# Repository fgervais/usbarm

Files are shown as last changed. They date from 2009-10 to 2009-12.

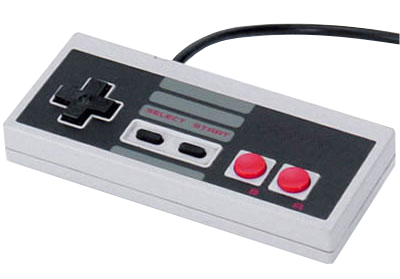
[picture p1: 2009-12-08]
Rapport/images/nes_controller1.png

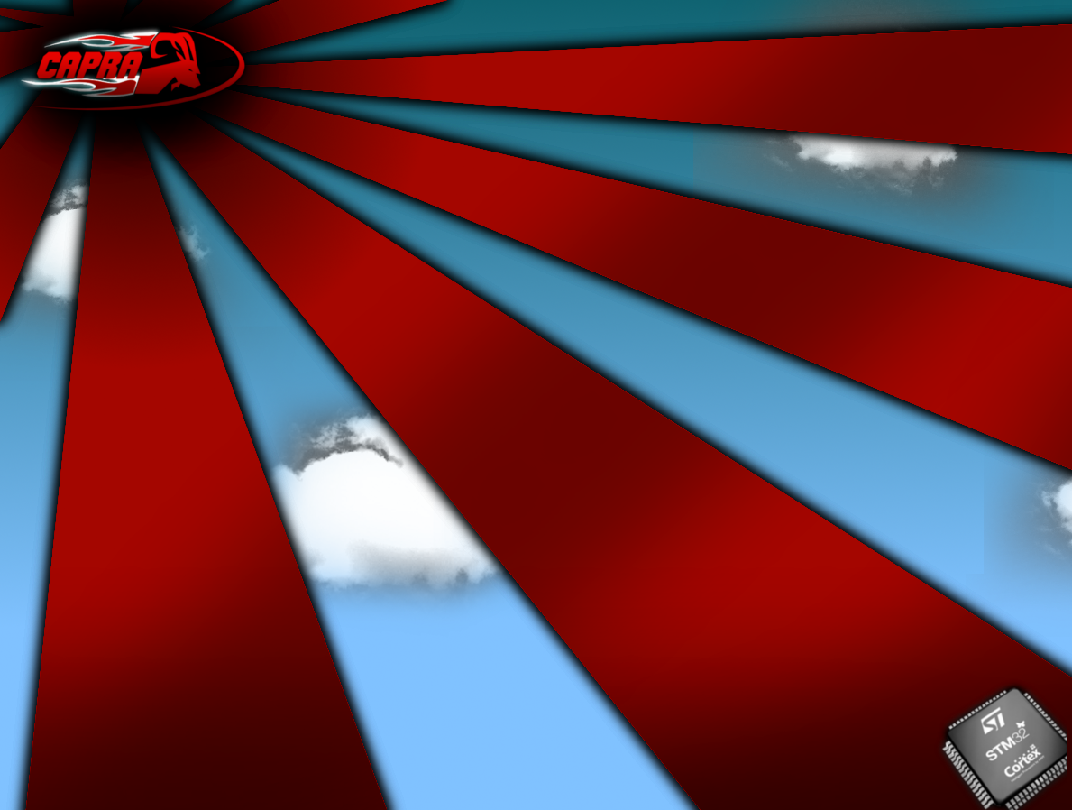
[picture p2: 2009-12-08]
Rapport/images/CapraPowerPointbg.png

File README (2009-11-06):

Note: This template has been built from a template done by Peter Harrison. His original README has been keept but renamed as README_LEGACY.
------------------

This folder contain...

These are some impotant things to keep in mind:

- There might be some peripheral conflict since some/all GPIO are multiplexed.

Here is how thing are done and what are the bad things that could happen.
The first time you ask STM32F103 class for something, it will configure everything
and the instance returned is guaranteed to work. However, it will not configure it
again as long as the program is running. So if you have two different peripheral 
that are using the same IOs, as soon has you ask for the second one, the first 
one will stop working.

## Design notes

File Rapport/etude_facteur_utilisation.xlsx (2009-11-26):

Fréquence d’opération SPI (Mhz) | Temps de la plus longue transaction (ms) | Temps du traitement (ms) | Facteur d'utilisation du processeur pour le service USB
0.28125 | 1.7030 | 0.1101 | 170.30%
0.5625 | 0.9065 |  | 90.65%
1.125 | 0.5083 |  | 50.83%
2.25 | 0.3092 |  | 30.92%
4.5 | 0.2097 |  | 20.97%
9 | 0.1599 |  | 15.99%
18 | 0.1350 |  | 13.50%

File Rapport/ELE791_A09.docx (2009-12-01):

ÉCOLE DE TECHNOLOGIE SUPÉRIEURE

UNIVERSITÉ DU QUÉBEC

rapport technique

PRÉSENTÉ À L’ÉCOLE DE TECHNOLOGIE SUPÉRIEURE

DANS LE CADRE DU PROJET DE FIN D’ÉTUDES

Restructuration du système de télécommandes pour les robots du club étudiant Capra

par

gervais, François

ST-onge, Rémi

présenté à

Jean-françois boland

montréal, le mercredi 9 décembre 2009

<titre du rapport TECHNIQUE>

<NOM, Prénom>

RÉSUMÉ

<Texte interligne simple>

TABLE DES MATIÈRES

Page

LISTE DES TABLEAUX

Page

LISTE DES FIGURES

Page

LISTE DES ABRÉVIATIONS, SIGLES ET ACRONYMES
Nom : | Description :
AI : | L'intelligence artificielle est défini par l’un de ses créateurs, Marvin Lee Minsky, comme « la construction de programmes informatiques qui s’adonnent à des tâches qui sont, pour l’instant, accomplies de façon plus satisfaisante par des êtres humains car elles demandent des processus mentaux de haut niveau tels que : l’apprentissage perceptuel, l’organisation de la mémoire et le raisonnement critique » http://fr.wikipedia.org/wiki/Intelligence_artificielle
ARM | Nom du manufacturier produisant le microcontrôleur que nous utilison
Bloc d'alimentation: | Le bloc d'alimentation est la composante qui fournis les tensions exigés par tous les composantes du robots. Le bloc utilise les batteries DC 24v et génère des tensions de 24v, 12v, 5v et 3.3v. C'est tensions alimentent l'ordinateurs, l'écran, tous les capteurs ainsi que les récepteurs de télécommandes et le contrôleur.
Capteurs : | Le terme Capteur signifie, dans le cas de nos robots, l'ensemble de périphérique utilisé pour détecté des objet et obstacles ainsi que pour se positionner. Les robots du club étudiant Capra utilisent une caméra, laser SICK LMS291, une boussole et accéléromètre en 3 dimensions, ainsi qu'un GPS NovAtel possédant une borde différentielle.
Contrôleur: | Composante crée par le club étudiant Capra permettant d'effectuer un lien entre l'ordinateur des robots et les interfaces d'entrées et sortie utilisé par le robots. Le controleur utilise un lien CanBUS pour communiquer avec l'ordinateur et utilise un port série RS232 pour communiquer avec la « drive » de moteurs tout en ayant la possibilité de contrôler les divers entrées et sortie du système. Le contrôleur est aussi utilisé pour faire l'asservissement des moteurs du robots
Cortex-M3 | Famille du microcontrôleur utilisé
CRC | Cyclic Redondancy Check
DC: | Le courant continu (qui peut être abrégé par CC, ou DC, pour Direct Current), est un courant électrique unidirectionnel : le courant circule continuellement dans le même sens, le déplacement des électrons se fait toujours dans le même sens. http://fr.wikipedia.org/wiki/Courant_continu
DE2 | Carte de développement produite par Terasic
Diagramme de Gantt: | « Le diagramme de Gantt est un outil utilisé en ordonnancement et gestion de projet et permettant de visualiser dans le temps les diverses tâches composant un projet. Il permet de représenter graphiquement l'avancement du projet. » http://fr.wikipedia.org/wiki/Diagramme_de_Gantt
Drive : | Le mot Drive vient de l'anglais et représente un contrôleur de moteur. Puisque notre robot contient déjà une pièce qui effectue le contrôle des moteurs, soit le contrôleur, nous utilisons le terme « drive » pour désigner le contrôleur de moteur Roboteq Ax1500. Il s'agit de la pièce qui gère la puissance de nos moteurs en lien avec des commandes RS232 reçu.
ÉLÉ | Nous parlons régulièrement de Batterie ÉLÉ, ou de la partie ÉLÉ du robot. Le robot est divisé en deux partie, soit par la partie électrique qui contient l'ordinateur, écran, bloc d'alimentation, le contrôleur ainsi que tous les capteurs utilisé dans le robots et bien entendu une batterie
HID | Human Interface Device
I/O | I/O vien de l'anglais, désignant les entrées et sortie d'un systeme. Il s'agit de l'abréviation de Input/Output
LED: | Une diode électroluminescente, abrégée sous les sigles DEL ou, plus couramment, LED (pour light-emitting diode) est un composant électronique capable d’émettre de la lumière lorsqu’il est parcouru par un courant électrique. http://fr.wikipedia.org/wiki/Diode_C3%A9lectroluminescente
Microcontrôleur: | Un microcontrôleur est un circuit intégré qui rassemble les éléments essentiels d'un ordinateur : processeur, mémoires et interfaces d'entrées-sorties. Les microcontrôleurs se caractérisent par un plus haut degré d'intégration, une plus faible consommation électrique, une vitesse de fonctionnement plus faible et un coût réduit par rapport aux microprocesseurs polyvalents utilisés dans les ordinateurs personnels. http://fr.wikipedia.org/wiki/Microcontr%C3%B4leur
MEC | La partie MEC du robot désigne la partie alimenté par la batterie MEC du robot. Elle est constitué de la « drive » de moteur et des moteurs eux même ainsi qu'une batterie.
Mode Intelligence artificielle | Le mode « Intelligence artificielle » est un mode de réception de la drive de moteur. Lorsque la drive est programmé en mode « Intelligence artificielle », elle s'attend à recevoir des données dans un protocole de communication RS232 qui ont le format !A7F. Ce qui signifie que le moteur A doit tourner à une vitesse de 7F (127) ce qui est la valeure maximal.
Mode Télécommande | Le mode « télécommande » est un mode de réception de la drive de moteur. Lorsque la drive est programmé en mode « télécommande », elle s'attend à recevoir des données sous forme de PWM, soit un signal de forme carré ou la largeur de la bande détermine la vitesse de chaque moteur.
NAK | Non Acknowledge
NES | Nintendo Entertainment System
Nintendo | Auteur de la console Nintendo Entertainment System
PID | Packet Identification
PWM : | La modulation de largeur d'impulsions (en anglais : Pulse Width Modulation, soit PWM), est une technique couramment utilisée pour synthétiser des signaux continus à l'aide de circuits à fonctionnement tout ou rien, ou plus généralement à états discrets.Le principe général est qu'en appliquant une succession d'états discrets pendant des durées bien choisies, on peut obtenir en moyenne sur une certaine durée n'importe quelle valeur intermédiaire. http://fr.wikipedia.org/wiki/Modulation_de_largeur_d%27impulsion
Récepteur : | Le récepteurs est la composante qui reçois les signaux électro-magnétique provenant des télécommandes que nous utilisons. Nous avons deux récepteurs similaire qui sont utilisé pour récupérer les signaux provenant de la télécommande du robot ainsi que les signaux provenant de l'arrêt d'urgence sans fil.
RS232 : | Le RS-232 est une norme standardisant un bus de communication de type série sur trois fils minimum (électrique, mécanique et protocole). Disponible sur presque tous les PC jusqu'au milieu des années 2000. http://fr.wikipedia.org/wiki/RS-232
SPI | Serial Peripheral Interface
Télécommande : | La télécommande est le périphérique que nous utilisons pour contrôler nos robots à distance par une intervention humaine. Cette télécommande est très pratique quand vient le temps de déplacer nos robots ou de faire des démonstrations publique.
UART: | UART est un terme qui vient de l'anglais, ce sont les initiales de : Universal Asynchronous Receiver Transmitter. L'UART est donc un émetteur-récepteur asynchrone universel. En langage courant, c'est le composant utilisé pour faire la liaison entre l'ordinateur et le port série . L'ordinateur envoie les données en parallèle (autant de fils que de bits de données). Il faut donc transformer ces données pour les faire passer à travers une liaison série qui utilise un même fil pour faire passer tous les bits de données. http://fr.wikipedia.org/wiki/UART
USB : | L’Universal Serial Bus (USB) est un bus informatique à transmission série servant à connecter des périphériques informatiques à un ordinateur. Le bus USB permet de connecter jusqu'à 127 périphériques à chaud et en bénéficiant du Plug and Play. http://fr.wikipedia.org/wiki/Universal_Serial_Bushttp://fr.wikipedia.org/wiki/Courant_continu
XBOX | Marque déposé de Microsoft pour sa console de jeux vidéo

# INTRODUCTION

Le club Capra a été fondé en 1996 par des étudiants, passionné de robotique, de l'école de technologie supérieure. Capra se spécialise dans la construction de robots autonome qui tentent de relever des défis au niveau de compétitions internationale dans le domaine de la navigation autonome. Grâce à l'implication d'une vingtaine de membre actif dans plusieurs domaines du génie tel que Mécanique, Électrique, Logiciel, Ti, Opérations et logistique ainsi qu'en production automatisée, le club est parvenu, cette été, à remporter un trophée pour une 3ieme place à la compétition de l'ION Automow (Institute of Navigation).

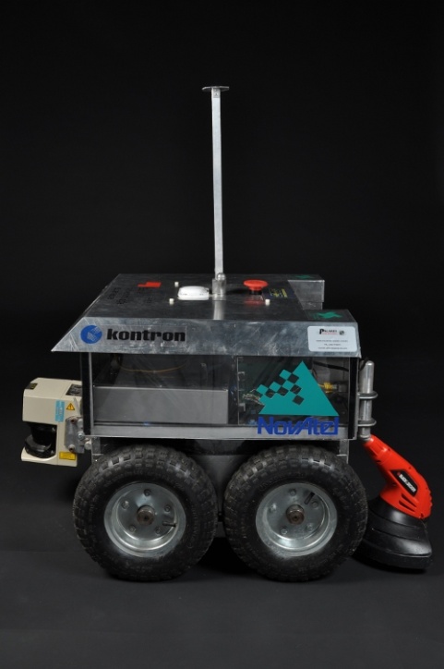
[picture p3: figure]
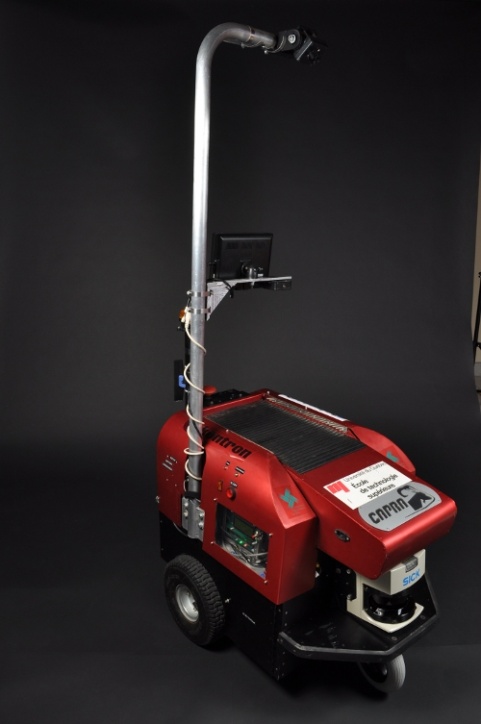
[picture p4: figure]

Pour le moment, le club Capra utilise deux robots fiables, soit RS3 et Herbinator. RS3, participe une compétition de parcours à obstacle dans lequel il doit parcourir un trajet qui lui est inconnu et qui est remplis d'embuche. Il doit atteindre la ligne d'arrivée, sans aucune intervention humaine plus rapidement que les autres équipes. Herbinator, pour sa part, est une tondeuse à gazon autonome capable de tondre des terrains de formes différentes tout en étant capable d'éviter les fleurs et le chien qui se ballade sur le terrain de la compétition.

Figure 2 RS3

Figure 1 Herbinator

Les deux robots, qui effectue des taches bien différente, ont des caractéristiques électronique et logicielle très semblables. Ils utilisent une panoplie de capteurs de toute sorte reliée à un ordinateur qui effectue le traitement de toutes ces données pour s'orienter et se déplacer en toute quiétude.

Le club travaille présentement à améliorer et maintenir ces deux robots dans le but d'obtenir une première place lors d'une future compétition. Cette année, nous nous dirigerons vers

C’est donc par l’expérience des compétitions passés, les démonstrations de robotiques auxquelles nous participons dans le but de représenter l’école de technologie supérieure de Montréal ainsi que les nombreux tests effectué tout au long de l’année que nous avons remarqué plusieurs problèmes relié au système de gestion des télécommandes de nos robots.

Cette année, nous partirons, dans la semaine du 30 mai 2010, deux équipes distincte, avec deux robots distincts à deux compétitions qui se dérouleront en même temps en sol américain. L’une sera à détroit dans l’état du Michigan et l’autre à Dayton dans l’état de l’Ohio.

Au cours de la prochaine année, le club étudiant aimerait régler des problématiques de mobilité des robots en améliorant l'implémentation de la télécommande qui permet de contrôler le robot à distance. Ces télécommandes sont utilisé lors des divers événements publicitaires ou de démonstrations publique que nous participons ainsi que lors de la réalisation de test ou l'on doit déplacer les robots dans des endroits stratégiques.

# CHAPITRE 1 Analyse de la problématique

## 1.1 Explication du système actuel

Pour bien être en mesure de comprendre les problèmes reliés au système de télécommande de nos robots, il importe de comprendre le fonctionnement de ceux-ci. Nous allons donc débuter par vous expliquer le principe de fonctionnement de nos robots.

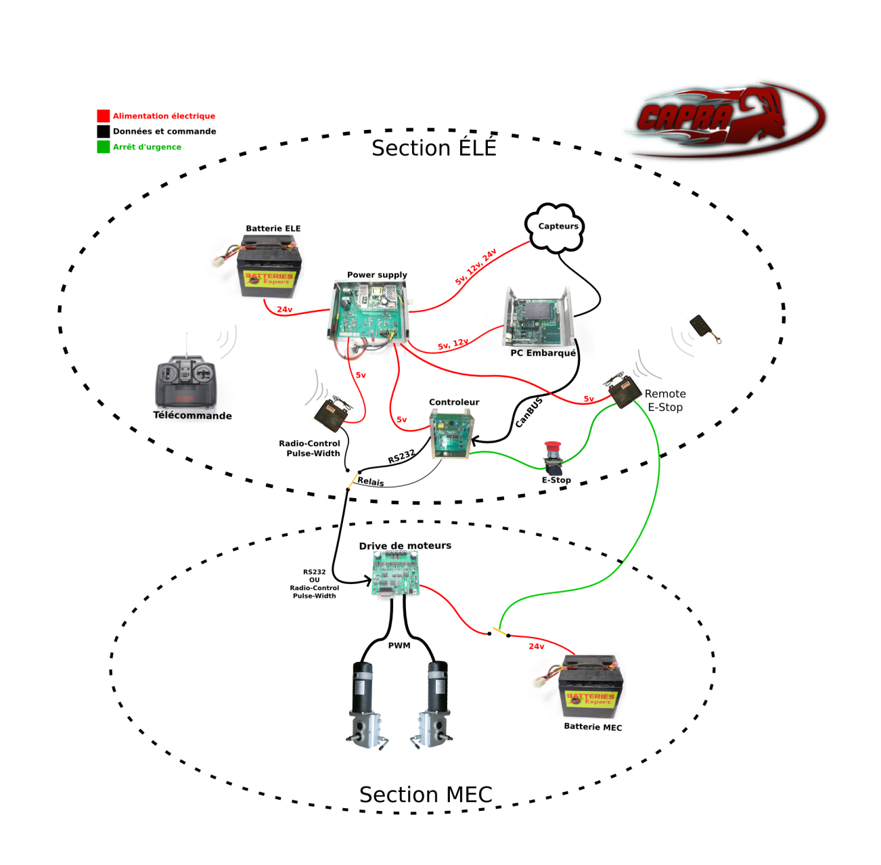
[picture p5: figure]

Figure 2 Schéma actuel des robots

Ce diagramme représente les diverses composantes du robot en lien avec le système de télécommande.

Globalement, le système actuel est divisible en deux partie. Une partie ÉLÉ et une partie MEC. La partie MEC est alimentée par la batterie MEC et contient la « drive » de moteur ainsi que les deux moteurs. La partie ELE, pour sa part, est alimenté par la batterie ELE et contient l'ordinateur embarqué, tous les capteurs, le contrôleur, le bloc d'alimentation, ainsi que les deux télécommandes et récepteurs. Les alimentations des deux parties sont importantes parce qu'elles sont, en bonne partie, une sources des problèmes reliés aux télécommandes. Nous pouvons aussi apercevoir dans le schéma le système d'arrêt d'urgence en vert.

La partie la plus importante se trouve à être la chaine de commande des moteurs. Pour commencer, les données peuvent provenir de l’intelligence artificielle qui se trouve dans le PC embarqué du robot. Les commandes sont transmises au contrôleur par le biais d’un port CANBUS. Par la suite, le contrôleur transmet ces données à la drive de moteur par un lien RS232 en passant par un relais qui aiguille les diverses sources de données pouvant se rendre à la drive. Finalement, la drive de moteur exécute les commande en envoyant les bonnes tensions aux moteurs.

Dans un autre ordre d’idée, il est possible d’utiliser la télécommande des robots. Le récepteur de cette télécommande utilise deux PWM ou la modulation de la largeur de bande représente l’état des deux contrôles sur la télécommande. Notre drive de moteurs est en mesure d’interpréter ces signaux si elle est programmée dans le mode PWM. Donc, pour utiliser cette télécommande, le contrôleur doit envoyer un message à la drive pour la programmer dans le mode PWM et ensuite changer l’état du relais pour aiguiller ce dernier sur l’entrée du récepteur de la télécommande. Si nous désirons revenir en mode intelligence artificielle, le contrôleur modifie l’état du relais pour aiguiller l’entrée sur le lien RS232 provenant du contrôleur et envoie encore une fois un message à la drive de moteur de se programmer en mode RS232.

De plus, les alimentations relié au système ont aussi une importance dans la problématique que nous allons vous expliquer.

Selon le diagramme, nous constatons aussi que les divers récepteurs et pièces sont tous alimenté par le bloc d’alimentation principale à l’exception de la drive de moteur qui elle est alimenté par la batterie Mec du robot. La drive de moteur se trouve donc sur une alimentation séparé du reste du robot.

## 1.2 Division en sous-problèmes

Cette structure nous apporte plusieurs problèmes de toute sorte.

Premièrement, la télécommande actuelle ne fonctionne que sur une très courte distance et la réception est, très souvent, mauvaise. Parfois le robot ne bouge plus du tout ou se déplace de manière très saccadé. La solution devra donc permettre une réception plus fiable et sur une plus grande distance.

De plus, la télécommande utilisée par Capra consume énormément et rapidement les piles. Plus les piles deviennent faible dans la télécommande, plus la réception est mauvaise par les robots. Les télécommandes utilisent chacune 8 piles AA et nous ne disposons pour l'instant que d'un seul chargeur permettant de charger 8 piles à la fois. Cette charge prend environ une journée complète. Pour charger les piles de nos deux télécommandes, nous devons impérativement les charger en deux jours, en s'assurant que quelqu'un soit présent au local du club étudiant pour effectuer une rotation des piles. La gestion de cette charge étant effectué par plusieurs personnes et la communication au sein du club étudiant étant relativement déficiente, la charge de ces piles est un véritable cauchemar. La solution devra donc faciliter le cycle de charges des piles de télécommandes.

Par la suite, les piles utilisées dans les télécommandes se déchargent par eux même. Si les piles sont oubliées dans la télécommande, malgré le fait que cette dernière soit éteinte, les piles se vident complètement en 24 heures. Si nous enlevons les piles de la télécommande, elles se vident tout de même par elle même en deux semaines. Il est donc impossible pour nous de tenir les piles chargé en tout temps. Si nous avons besoin d'utiliser la télécommande rapidement, les chances sont très faibles que nous ayons des piles chargées.

Ensuite, la configuration actuelle de la télécommande implique que la drive de moteur soit configuré en mode « Télécommande » pour traiter les signaux provenant de la télécommande et en mode « Intelligence artificielle » pour traiter les signaux provenant de l'intelligence artificielle. Cette programmation cause beaucoup de problèmes parce qu'elle n'est pas fiable et qu'il est difficile pour nous de nous assurer que la « drive » est dans le mode désirée. Il arrive fréquemment que nous devons brancher un ordinateur dans la « drive » pour la reprogrammer dans le but de pouvoir utiliser la télécommande. Cette programmation est expliqué par le fait que l'intelligence artificielle utilise le protocole RS232 pour communiquer avec la « drive » et la télécommande utilise un PWM (pulse width modulation) pour transmettre les vitesses de chaque moteurs. De plus, nous avons récemment appris, à l’aide du manuel d’utilisateur de la drive de moteur, que nous pouvons la programmer un maximum de 1000 fois. Pour l’instant, nous la programmons au minimum 3 fois à chaque fois que nous utilisons le robot et nous commençons aujourd’hui à avoir beaucoup de problèmes avec nos drives de moteurs qui sont probablement lié de près à cette indication. Le club Capra désire donc trouver une solution qui permet d'éliminer le besoin de reprogrammer la « drive » de moteur lorsqu'on passe du mode « télécommande » au mode « intelligence artificielle ».

Finalement, lorsque nous désirons utiliser la télécommande pour contrôler les robots, nous devons allumer l'ordinateur du robot, qui lui fait démarrer le bloc d'alimentation qui alimente toutes les composantes électronique du robot (capteur, contrôleur, écran, ordinateur, etc). Le fait de tout alimenter le robot lorsque nous n'utilisons que très peu de matériel devient problématique puisque les piles du robot se vident très rapidement. En mode télécommande, le robot devrait alimenter seulement les composantes nécessaires à la motricité sans alimenter les capteurs, l'ordinateur, l'écran ainsi que tous les autres périphériques inutile au mouvement en mode télécommandé.

## 1.3 Étude de la complexité

<Texte>

# CHAPITRE 2 Choix d’une solution

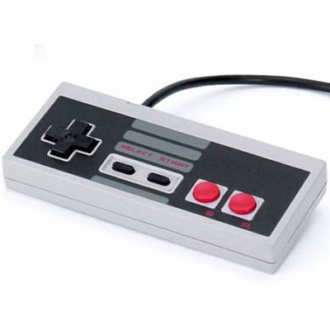
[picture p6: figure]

## 2.1 Jet d’idées

Notre idée de départ était d’intégrer une télécommande de Nintendo 8 bit.

Par la suite, nous avons pensé garder la même télécommande que nous avons actuellement pour nos robots mais en la branchant dans un système qui pourrais convertir le PWM en RS232.

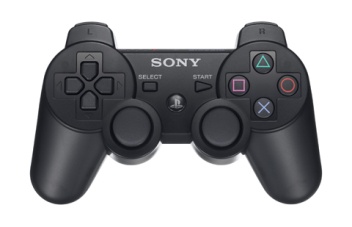
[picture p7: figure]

Nous avons aussi analyser la possibilité d’utiliser une télécommande de Playstation 3 sans fil

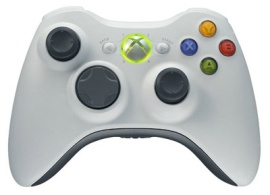
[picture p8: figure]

Et finalement une télécommande de XBOX 360 sans fil

## 2.2 Définition des concepts

Premièrement la télécommande de Nintendo à un grand avantage et un grand désavantage. Premièrement, elle possède un fil. Ce fil nous assure une communication parfaite sans aucune perte de donnée et qui est par le fait même extrêmement fiable. De plus, le protocole de communication de cette télécommande est très simple et facile à intégrer. Son désavantage est qu’elle possède un fil. En effet, notre portée avec le robot se trouve à être très limité. De plus, ces boutons sont de type « Tout ou rien » ce qui pourrais être dangereux dans le cas de notre robot puisque nous n’aurions aucun contrôle de la vitesse du robot mais seulement de la direction dans lequel il se dirige.

Nous avons ensuite analysé la possibilité de garder nos télécommandes actuelles en les modifiant afin de régler certain problèmes. Premièrement, cette télécommande devra être branchée dans une carte qui convertirais le PWM en RS232 pour éliminer le problème de reprogrammation de la drive de moteur. De plus, des piles au lithium ou au nickel devraient être installé pour augmenter la durée de vie de ces dernières. Le fait de modifier les piles devraient, en temps normal, augmenter la puissance de la transmission et par le fait même augmenter la portée du système.

Nous avons ensuite analysé la possibilité d’inclure une télécommande de Playstation 3 sans fil. Cette télécommande à un grand avantage, soit celui de d’avoir une pile qui à fait ces preuves. De plus, la charge de cette pile peut être assurée tout simplement par le branchement d’un câble USB avec un ordinateur personnel. Cette télécommande à par-contre un désavantage. Elle utilise, comme la plupart des télécommandes de sa génération, la technologie Bluetooth pour communiquer avec les récepteurs. Cette technologie bien qu’efficace ne possède une portée que d’environ 10m de rayon, ce qui est insuffisant pour nos besoins.

Finalement, la télécommande de XBOX 360 à aussi le même avantage que la télécommande de Playstation, soit le fait qu’elle possède une batterie au lithium intégré qui se charge par un simple câble USB relié à un ordinateur personnel. Cette télécommande possède un autre avantage de taille : Son protocole de transmission des données se fait par un lien de communication fermé pour lequel les détails ne sont pas vraiment disponibles par Microsoft mais nous savons qu’elle n’utilise pas la technologie Bluetooth. Après avoir effectué plusieurs test, nous nous sommes aperçu que la portée de cette télécommande dépassent amplement nos attentes et nos besoins.

## 2.3 Choix d’une solution

Après de longue discutions, nous avons choisis d’intégrer la télécommande de XBOX à notre système. Ce choix étant risqué étant donné la complexité de l’intégration du USB dans un microcontrôleur, nous avons choisis d’implémenté en parallèle la conversion du PWM de nos commandes actuelles dans notre projet. Le choix de garder la télécommande RF actuelle implique de modifier cette dernière dans le but d’y intégrer une pile au lithium ou au nickel pour augmenter la durée de vie de ces piles ainsi que sa portée. Notre système fonctionnera comme suit : Nous aurons une carte dans laquelle nous brancherons les deux télécommandes (la télécommande de XBOX 360 et la télécommande RF actuelle des robots). Nous brancherons aussi dans cette carte un lien RS232 avec le contrôleur et un autre lien RS232 avec la drive de moteur. De cette manière, en temps normal, nous pourrons simplement répéter les données provenant du contrôleur vers la drive de moteur et ce sera complètement transparent pour l’intelligence artificielle. Les commandes obtenu provenant des télécommandes serons convertis en RS232 sous le même format utilisé par la contrôleur et un système de gestion de priorité (Multiplexeur) aura pour tache de diriger les bons signaux aux bon endroit. De plus, cette carte aura pour tâche d’alimenter les récepteurs des télécommandes et cette carte sera alimenté par la batterie MEC du robot. Ce qui aura pour conséquence d’obtenir la possibilité d’utiliser les télécommande avec tout simplement une batterie MEC et sans même avoir le besoin de démarrer la section ÉLÉ du robot. De plus, le système d’arrêt d’urgence sera modifié pour être controlé à partir de cette carte aussi dans le but de pouvoir débloquer les moteurs sans avoir besoin d’alimenté la section ÉLÉ du robot.

Le schéma suivant explique la solution retenue de manière plus visuelle :

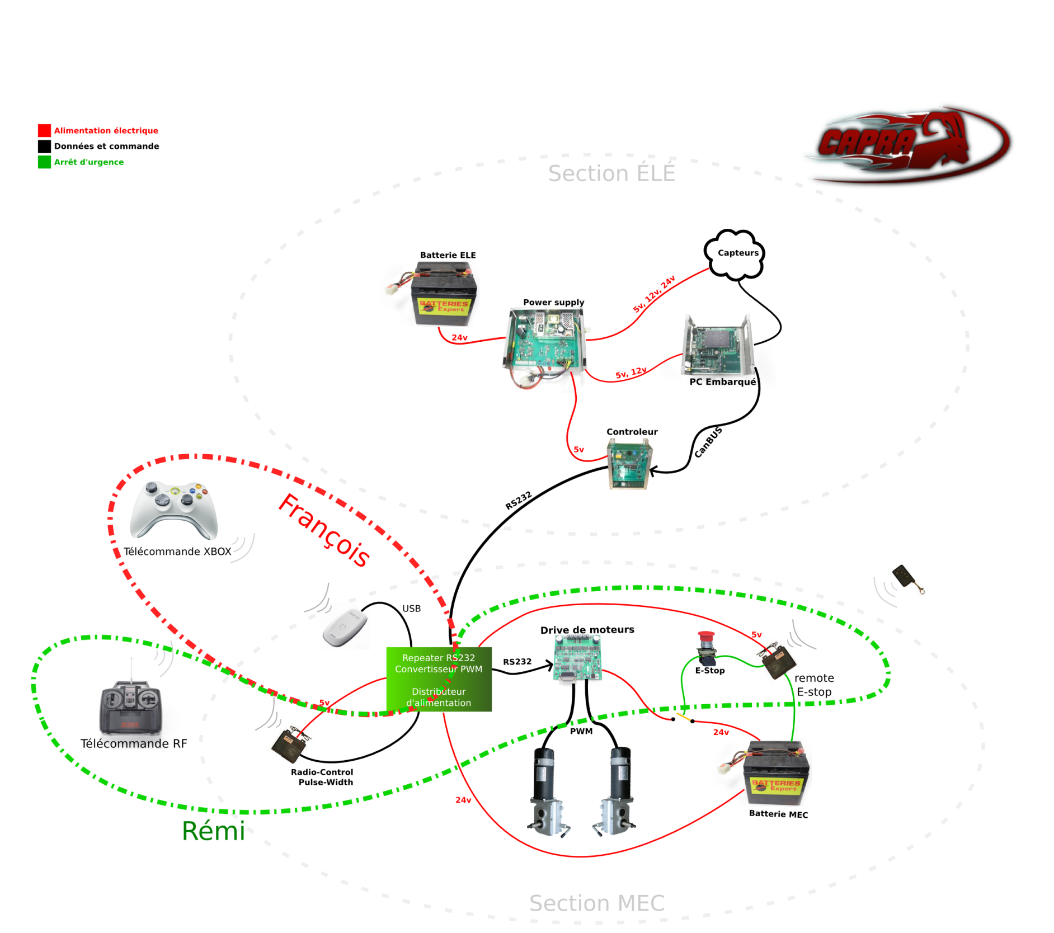
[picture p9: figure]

Figure 3 Schéma de la solution

# CHAPITRE 3 Risques et opportunités

## 3.1 Risques

- Les outils de compilation pour le microcontrôleur choisi ne sont pas disponibles.
- L’utilisation du ARM pourrait être plus complexe que prévue notamment au niveau des interruptions.
- La familiarisation des membres avec la programmation orientée objet dans un microcontrôleur peut être longue
- La création du circuit imprimé peut être plus longue que prévue
- Il pourrait être difficile de trouver un contrôleur USB à la fois facile d’utilisation, avec une bonne documentation et fournis sur une plateforme de prototypage.
- Dépendamment de la vitesse de la communication minimal entre le microcontrôleur et le contrôleur USB, il faudrait peut être produire nous même la plateforme de prototype ce que pourrait grandement jouer sur notre emploi du temps serré.
- La communication entre le microcontrôleur et le contrôleur USB pourrait être difficile à déverminer.
- Comme la vitesse des transactions USB est très rapide, certains problèmes liés à la fréquence élevée pourraient survenir. De plus, les transactions du bus seront difficiles à analyser.
- Plusieurs pièces devront être commandés sur Internet et ceci le plus tôt possible. Ceci rentre en conflit avec le fait que le contrôleur USB n’est pas choisi avant la moitié du projet. De plus le projet ne pourrait surement pas être fait dans les temps si certaines pièces arrivent endommagé ou si nous endommageons une pièce durant le développement.
- Les commandes venant de la télécommande XBOX devront être acquises par la lecture du code de pilotes du noyau linux et l’ingénierie inverse à l’aide d’un analyseur USB. Cette tâche pourrait possiblement être trop compliqué et prendre beaucoup plus de temps que prévue.

Opportunités

- La carte de développent DE2 est disponible à l’école et inclue un contrôleur USB. Celle-ci pourrait possiblement être utilisée.
- Batterie Expert est l’un des commanditaires du club étudiant Capra et pourrais nous donner des informations précieuse quant à la modification de la télécommande actuelle.
- L’existance d’un équipe logiciel au sein du club Capra pourra très probablement nous aider à planifier la gestion du code à l’intérieur du microcontrôleur.
- Labo circuit est aussi un des commanditaires du club étudiant Capra et pourrais possiblement nous fournir le circuit imprimé.

# CHAPITRE 4 Réalisation

## 4.1 Modification de la télécommande actuelle

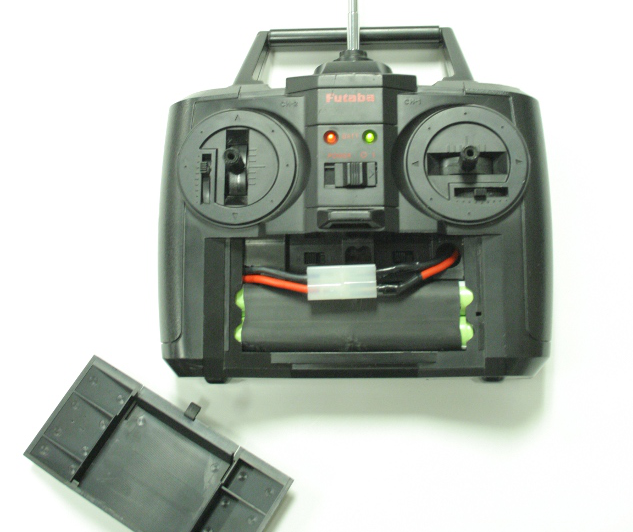
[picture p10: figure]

Pour débuter, nous nous sommes informé au près de Batterie Expert dans le but d’avoir plus amples informations au sujet des piles en général. Après avoir longuement discuté avec eux, nous avons fait un choix de piles. Nous avons choisis d’acheter un chargeur à batterie ainsi que de se faire fabriquer sur mesure un pack de batterie composé de 8 cellules au nickel permettant d’obtenir 2400mah, ce qui était près des spécifications des piles rechargeable que nous disposons au format AA à l’intérieur de notre télécommande. Par la suite, nous avons démonté et modifié l’intérieur de la télécommande à l’aide d’un Dremel dans le but d’enlever complètement le support de batterie AA à l’intérieur dans le but d’y intégré le pack de batteries. Puisque ces batteries ne peuvent maintenant plus être retirées de la télécommande, nous avons utilisé un connecteur à l’intérieur du compartiment à batterie qui permettra de brancher directement la batterie dans le chargeur sans la retirer du compartiment de la télécommande. Cette modification à été apporté a notre télécommande il y a maintenant plus de trois mois, et la pile est encore chargée! La durée de vie de cette pile est incroyable longue. De plus, comme prévu, la portée de la télécommande à été amélioré considérablement.

## 4.2 Choix du microcontrôleur

Notre système comprenant maintenant deux port série, un entrée de capture de PWM ainsi que le besoin d’un support USB Host, nous avions besoin d’un microcontrôleur capable de gérer le tout. Nous avons regardé plusieurs microcontrôleurs soit un Atmega32, un Atmega128 et un Arm Cortex M3. Nous avons finalement choisis le Arm Cortex M3 pour deux raison. Pour commencer, sa puissance de calcul est définitivement plus grande que celle du Atmega32 et du Atmega128. Avec sa fréquence d’horloge cadencée à 72 MHz et plusieurs technologies telles que son pipeline et la possibilité de faire des accès DMA était très prometteur. De plus, ce microcontrôleur nous était inconnu et il est maintenant plus populaire que jamais puisqu’il fait aujourd’hui parti de plusieurs produit qui ont fait leurs preuves comme par exemple le IPhone de Apple qui utilise un autre microcontrôleur Arm très semblable au Cortex M3. Nous avons aussi choisis ce processeur par la possibilité de développer en C++ orienté objet, ce qui nous a permis de concevoir une architecture claire et qui resteras hautement maintenable dans le futur, ce qui est une chose souvent négligé au sein des clubs étudiants.

## 4.3 Compilation et configuration du compilateur

## 4.4 Architecture de notre système (UML)

## 4.5 Communication RS232

## 4.6 Capture du PWM de la télécommande

## 4.7 Implémentation du système de choix de priorité des sources

Notre carte à pour tache de recevoir des données provenant de diverses sources, soit, la télécommande de XBOX 360, du

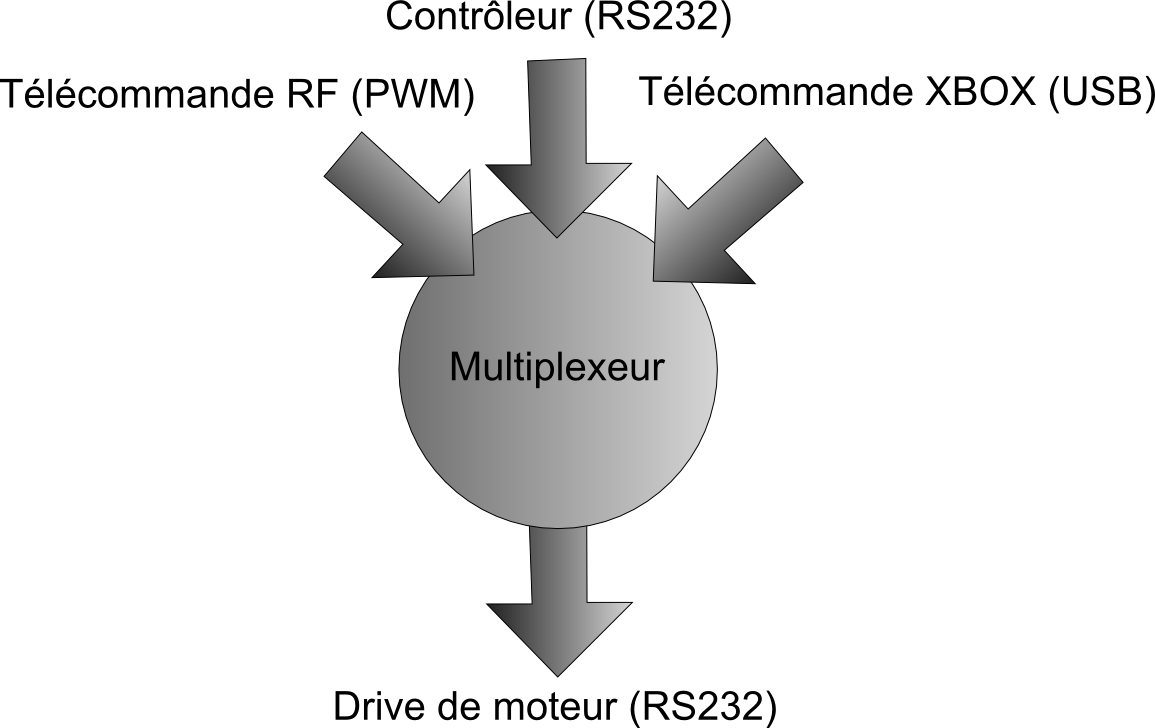
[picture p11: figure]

## 4.8 Choix du contrôleur USB

Le choix du contrôleur n’est pas chose facile. Plusieurs critères doivent être tenu en compte. Dans notre cas, les principaux étaient les suivants en ordre de priorité :

- Support du mode de communication USB par interruption
- Facilité d’accès à la documentation
- Facilité de raccord au microcontrôleur
- Faible à moyen niveau d’abstraction pour ne pas perdre le coté éducatif

Le contrôleur choisi est le MAX3421E de la compagnie Maxim. Cette puce supporte tous les modes de communication USB soit Control, Bulk, Interrupt et Isochronous. De plus, elle est pourvue d’une fiche technique, d’un guide de programmation et d’un exemple couvrant l’énumération. Du coté de l’abstraction, ce contrôleur prend soin de la couche 1 de la communication. En d’autre terme, outre le fait d’envoyer le bon niveau sur les lignes de transmission, il s’occupe d’envoyer le PID, du numéro de séquence des paquets, et d’une certaine partie de la gestion d’erreur. Pour les curieux, ceci consiste principalement en le calcule du CRC et la vérification de celui-ci lors de la réception. De plus, si le CRC permet de détecter une erreur, le contrôleur fera lui-même la demande du même paquet à nouveau. Il est à noter que ceci peut avoir un effet pervers. En effet lors de la conception du pilote, certaines erreurs d’implémentation peuvent être cachées dû au fait que le contrôleur USB redemande automatiquement les paquets en cas d’erreur.

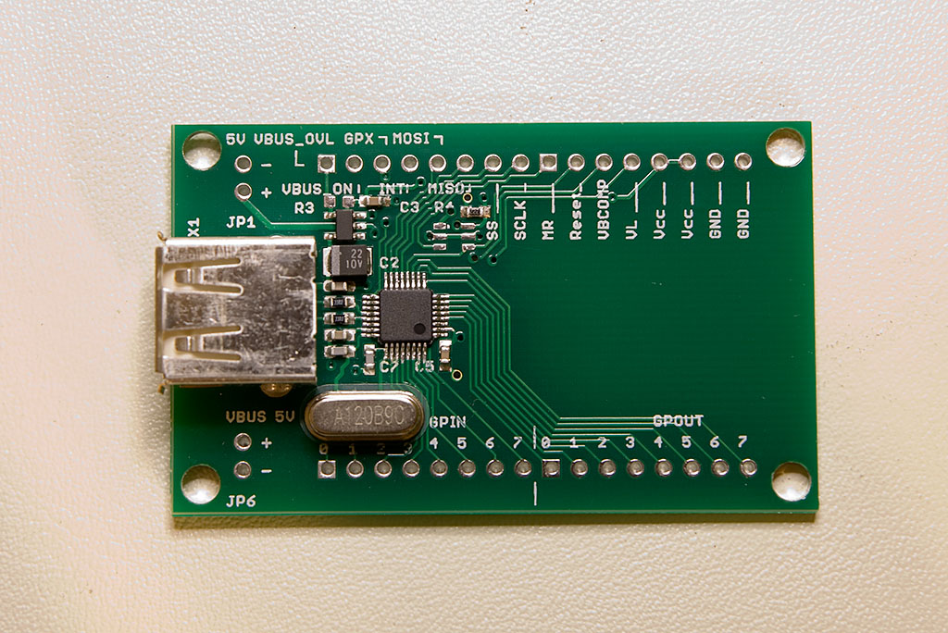
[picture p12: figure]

## 4.9 Conception du pilote USB

### 4.9.1 Détection du périphérique

### 4.9.2 Énumération du périphérique

### 4.9.3 Requêtes HID

Tel que mentionné précédemment le USB comporte plusieurs mode de fonctionnement soit Control, Bulk, Interrupt et Isochronous. Cependant, ceci reste assez large quand on considère tous les périphériques USB disponible. C’est pourquoi ceux qui ont développé la spécification USB ont aussi mis en place des classes de périphérique. Ceci permet de simplifier le développement de pilotes car tous les périphériques faisant partie d’une même classe ont le même mode de fonctionnement. Par exemple le HID est une classe du mode de transmission Interrupt. Cette classe définit qu’un périphérique doit envoyer et recevoir l’information sous forme de rapport. Il est important de mentionner que la réception d’un rapport par un périphérique HID est optionnelle selon la norme. Par contre, la télécommande Xbox implémente cette fonctionnalité et in en sera question dans la section correspondante.

Afin de faire la demande d’un rapport, l’hôte doit envoyer un jeton au Endpoint Interrupt avec un bit indiquant une direction entrante. Une fois ce jeton reçu, le périphérique USB enverra un rapport si celui-ci à de l’information à partager. Dans le cas échéant, il envoie le paquet NAK. Le même principe est utilisé pour envoyé un rapport au périphérique seulement dans ce cas le bit de direction du jeton indique une direction sortante. Une fois ce jeton envoyé, l’hôte envoie le rapport au périphérique. Comme vous pouvez le constater, le bit de direction indique toujours une direction par rapport à l’hôte.

Pour une meilleure compréhension de la communication USB par interruption en général, la meilleure façon est probablement de jeter un œil au diagramme du livre « USB Complete ».

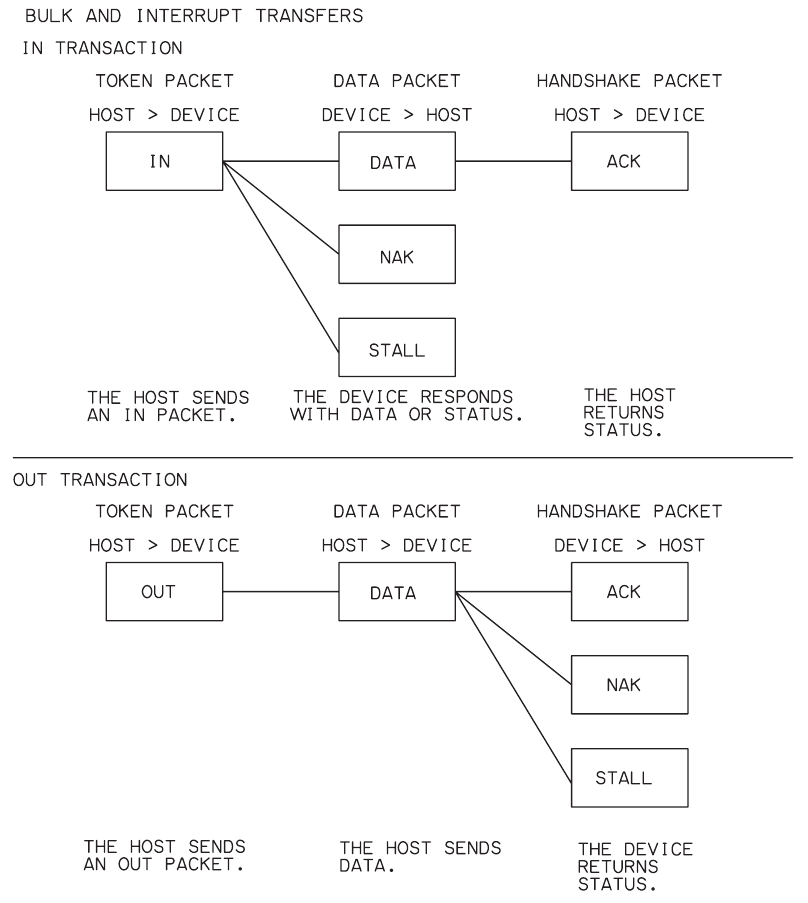
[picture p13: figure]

Il est important de noter que bien que le mode de transmission HID définit la communication par rapport, celui-ci ne définit pas le format des rapports sauf pour les périphériques courants. Plus d’information sur les rapports sont fournis dans la section correspondante.

### 4.9.4 Période des requêtes HID

Selon le standard USB, un périphérique se conformant à la norme HID doit fournir le temps entre les requêtes à l’hôte lors de l’énumération. Pour un bon fonctionnement du périphérique, ces temps doivent être respectés. Dans le cas de la télécommande du XBOX, celle-ci doit être interrogé tous les millisecondes. Le diagramme de séquence suivant indique la façon de faire au niveau du logiciel.

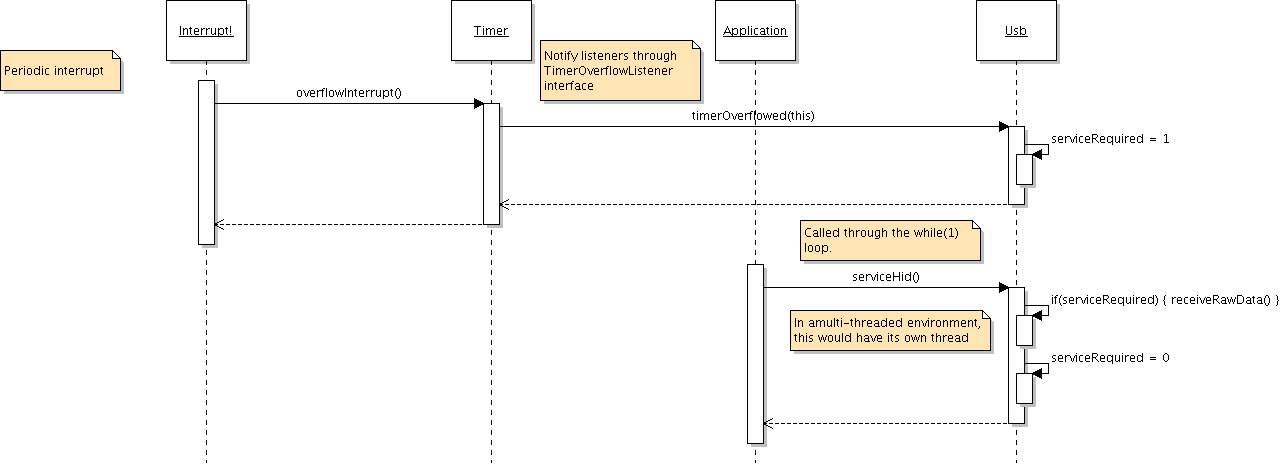
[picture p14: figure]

À tous les millisecondes, un timer déborde et met à jour un fanion indiquant que le service du périphérique est requis. Une fois ceci fait, la prochaine fois que le processeur aura le temps, il fera une requête à la télécommande.

En utilisant l’analyseur logique, il est possible de regarder les transactions entre le processeur et le contrôleur USB pour voir si ces délais sont respectés en pratique.

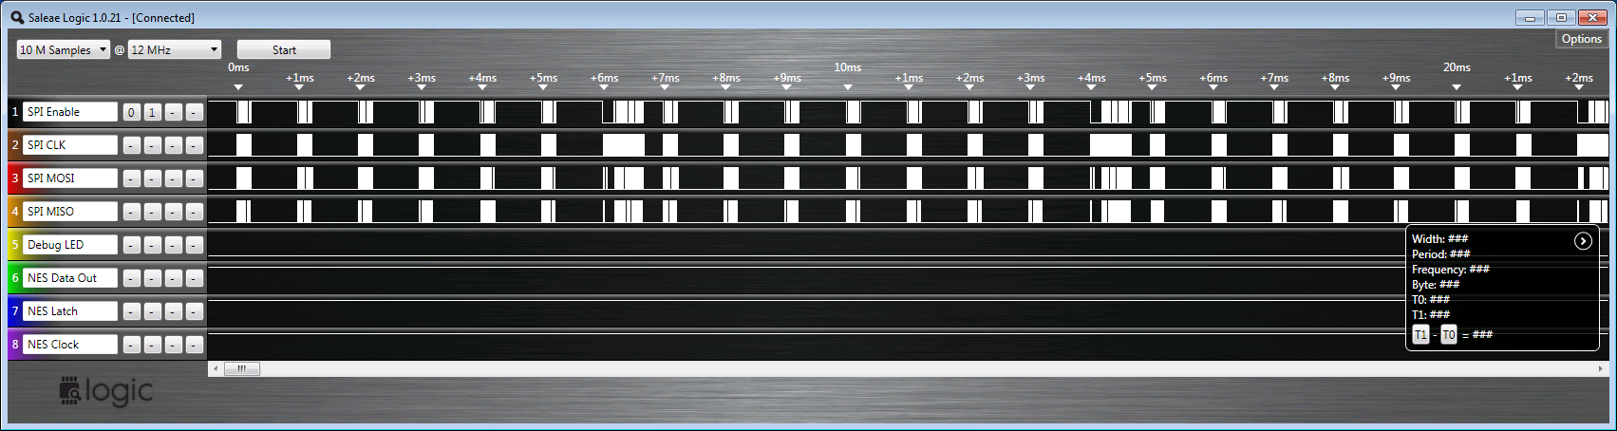
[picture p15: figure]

La communication entre le microcontrôleur et le contrôleur USB se fait en SPI. Lorsque nous ne voyons aucune activité sur le bus, c’est que les transactions son terminé pour cette période de temps. Nous remarquons que le processeur passe beaucoup de temps dans ces communications mais ceci est une facette que nous traiterons dans les prochaines sections.

### 4.9.5 Temps alloué au service USB

Lors du service du périphérique USB, le microcontrôleur communique constamment avec le contrôleur USB par SPI. Il est donc possible de voir facilement le temps alloué pour ce service en regardant la communication entre ces deux puces. De plus, nous pouvons en déduire le temps libre pour les autres tâches du processeur. Sur cet ordre d’idée, il est important de réduire le temps des communications aux maximums car plus le facteur d’utilisation du processeur se rapproche de 1, plus nos chances de respecter le temps entre les services HID deviennent faible. Afin de mettre cela en perspective, une étude plus poussé de ces communications SPI s’impose.

Il est important de mentionner que notre analyse sera basée sur la communication la plus longue. Dans notre cas, cette communication se produit lorsqu’il y a un changement d’état de la télécommande de XBOX.

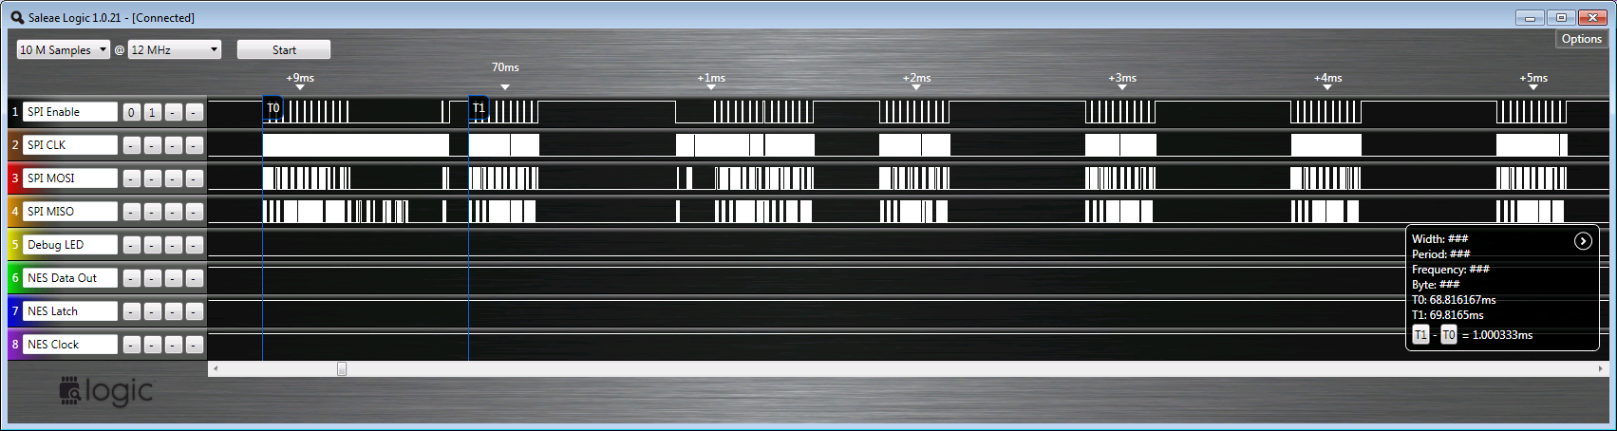
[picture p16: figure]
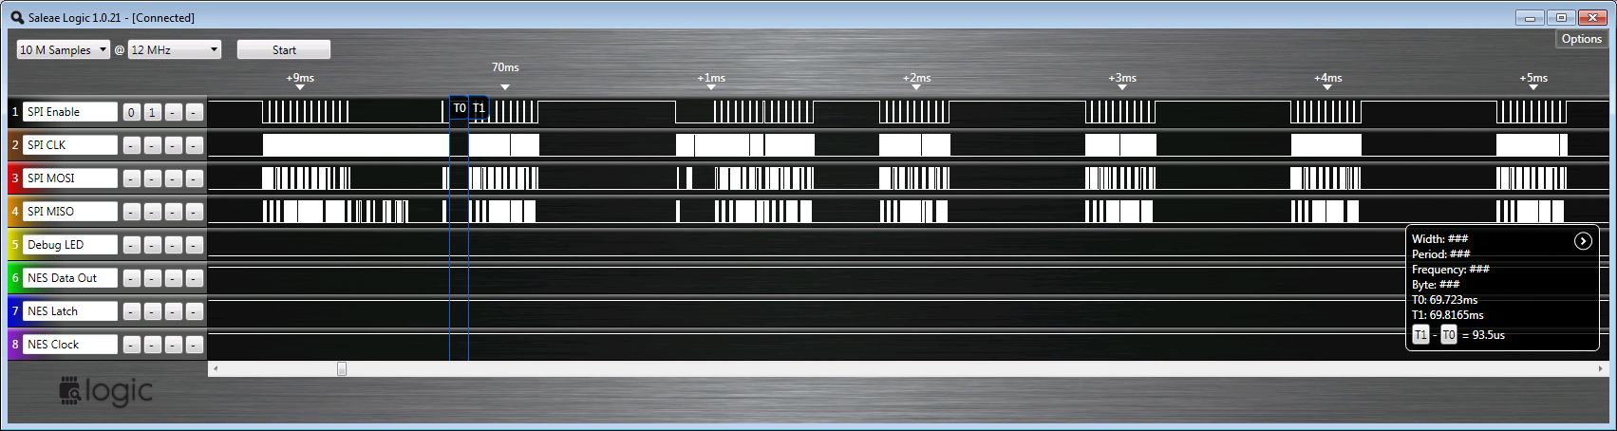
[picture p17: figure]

Les deux captures précédente démontre que sur une période de 1 milliseconde, il reste 93.5 microsecondes de libre au processeur. Ceci revient à dire que le service USB le plus long dure 0.9065 millisecondes. Comme nous connaissons la vitesse de transmission et le nombre d’octet transmit, il est possible d’en déduire le temps requis pour le traitement du USB. Voyons tout ceci en détail.

Cette communication est composée de 56 octets. La fréquence d’opération du SPI pour cet exemple est la fréquence des périphériques divisée par 128. Dans notre cas, a fréquence des périphérique est la même que la fréquence du processeur une fois multipliée, soit 72Mhz. Ceci donne une fréquence du SPI de 562.5 kHz. Avec 8 bits par octet, la communication de 56 octets devrait prendre 0.7964 milliseconde.

À l’aide de ce résultat nous en déduisons que le service USB pour la communication la plus longue requière 0.1101 millisecondes du processeur. Il est maintenant possible d’observer le facteur d’utilisation du processeur pour le service USB en fonction de la fréquence SPI de façon théorique. Nous faisons l’expérience sur la plage de fréquence supportée par le Cortex-M3 et possible d’atteindre avec le MAX3421E.

De ce graphique il est possible de déterminer le meilleur compromis en un coup d’œil. Il est bon de prendre note qu’un facteur d’utilisation de plus de 100% indique qu’il nous est impossible de finir notre service du périphérique en 1 millisecondes. Nous allons donc prendre constamment du retard ce qui risque de mettre le périphérique USB dans un mode d’opération imprévisible. Une fréquence du bus SPI de moins de 500 kHz est donc déconseillée.

### 4.9.6 Décodage des rapports HID

Lorsque nous faisons le service du périphérique USB, nous ne demandons en fait qu’un rapport de ce dernier. La norme USB à établie le format du rapport pour certains périphériques standard comme le clavier et la souris d’un ordinateur. Cependant, le constructeur est libre de choisir le format qu’il désire lors de la conception de son périphérique. Comme nous pouvons l’imaginer, Microsoft à utilisé son propre format pour sa télécommande.

Afin de bien définir le format du rapport, j’ai utilisé le site officiel de l’ingénierie inverse du XBOX 360, free60.org. Celui-ci ne dispose d’information que pour la télécommande avec fil mais ceci est néanmoins en très bon point de départ. Ce site définit le rapport comme suit :

Offset | Length (bits) | Description | Windows driver
0x00.0 | 8 | Message type
0x01.0 | 8 | Packet size (20 bytes = 0x14)
0x02.0 | 1 | D-Pad up | D-Pad up
0x02.1 | 1 | D-Pad down | D-Pad down
0x02.2 | 1 | D-Pad left | D-Pad left
0x02.3 | 1 | D-pad right | D-Pad right
0x02.4 | 1 | Start button | Button 8
0x02.5 | 1 | Back button | Button 7
0x02.6 | 1 | Left stick press | Button 9
0x02.7 | 1 | Right stick press | Button 10
0x03.0 | 1 | Button LB | Button 5
0x03.1 | 1 | Button RB | Button 6
0x03.2 | 1 | Xbox logo button
0x03.3 | 1 | Unused
0x03.4 | 1 | Button A | Button 1
0x03.5 | 1 | Button B | Button 2
0x03.6 | 1 | Button X | Button 3
0x03.7 | 1 | Button Y | Button 4
0x04.0 | 8 | Left trigger | Z-axis down
0x05.0 | 8 | Right trigger | Z-axis up
0x06.0 | 16 | Left stick X-axis | X-axis
0x08.0 | 16 | Left stick Y-axis | Y-axis
0x0a.0 | 16 | Right stick X-axis | X-turn
0x0c.0 | 16 | Right stick Y-axis | Y-turn
0x0e.0 | 48 | Unused

Afin de vérifier la concordance avec la télécommande sans fil, un analyseur USB fût utilise. En bref, cet outil permet d’afficher toutes les transactions USB faite par le noyau du système d’exploitation. Voici un rapport USB visualisé à l’aide d’un tel analyseur :

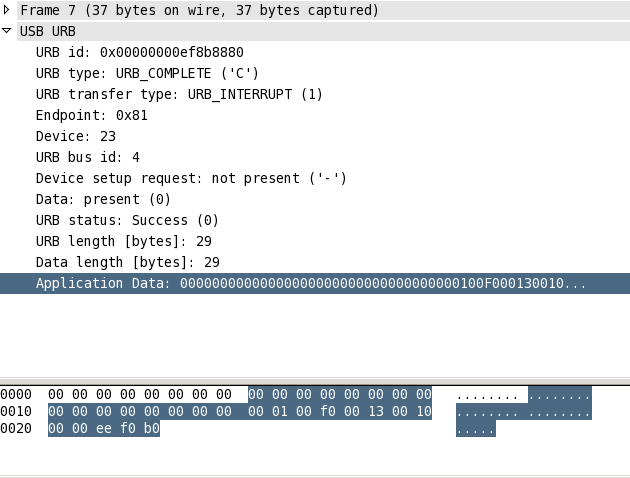
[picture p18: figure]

Lors que nous enfonçons le bouton A de la télécommande, nous recevons le message de la capture précédente. Il et important de mentionner que le rapport commence à l’adresse 0x18 sur les captures. Ce rapport en particulier commence donc par les octets 0x00, 0x01, 0x00, 0xF0, 0x00, 0x13. Selon le tableau faisant la description du rapport, le bit à la position 0x03.4 devrait être à 1. Cependant ce n’est pas le cas ici. Par contre, le bit 0x07.4 est à 1 ce qui nous donne une piste. L’analyse du code source du pilote xboxdrv-linux permettra de vérifier nos présomptions. En effet, ce code supporte la télécommande sans fil. La section traitant les évènements de la télécommande est particulièrement intéressante :

Cette condition vérifie l’information du rapport et ci celui-ci commence par la séquence 0x00, 0x01, 0x00, 0xF0, 0x00, 0x13, il transforme cette information en un message de la télécommande de type XBOX 360 *avec* fils mais avec un décalage de 4 octets. D’où le passage de l’adresse de la quatrième case de tableau. En d’autre terme, l’octet 4 correspond à l’octet 0 du rapport de la télécommande avec fil. Ceci est très intéressant car en regardant la capture prise avec l’analyseur USB nous constatons la même séquence de début de rapport. De plus lorsque nous avons enfoncé le bouton A, le bit à la position 0x07.4 était à 1. En tenant compte du décalage de 4 octets, ceci correspond au bit 0x03.4 du tableau ce qui est bien le bouton A.

Lors de l’implémentation du pilote, nous avons procédé à plusieurs autres tests qui ont confirmé la correspondance entre l’information reçu et le tableau de free60.org. La figure suivante est un rapport capturé à l’aide de l’analyseur logique et démontre la cas où le bouton A est enfoncé. Ce paquet est exactement le même que celui reçu avec l’analyseur USB.

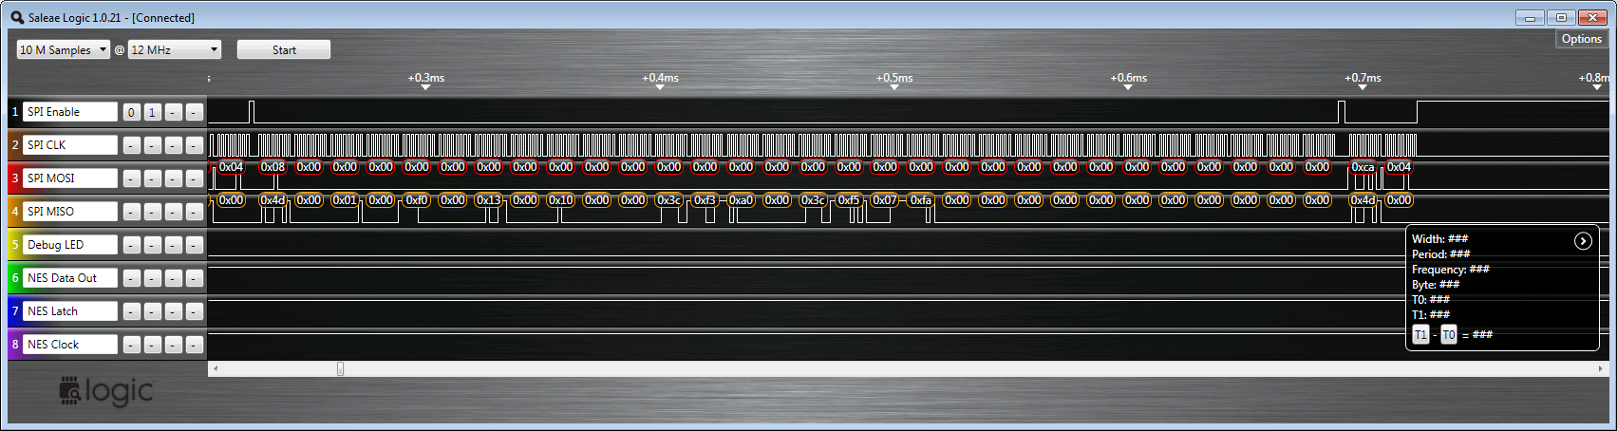
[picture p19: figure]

### 4.9.7 Rapports HID sortant

Comme introduit précédemment, la télécommande est conçue pour recevoir des rapports sortants. En d’autres termes, des rapports de l’hôte vers le périphérique. Dans notre cas, ces rapports sont utilisés essentiellement pour contrôler les LED sur la télécommande. Ceci est un détail important car par défaut les 4 LEDs flash indéfiniment ce qui est agaçant pour l’utilisateur même lors d’une courte utilisation.

Encore une fois, le format du rapport à dû être déterminé en utilisant plusieurs sources d’information. Le site Internet free60.org fût le point de départ. Ce site fournit un format de rapport sur 3 octets incluant une certaine commande. La liste de commande est la suivante :

Pattern | Description
0x00 | All off
0x01 | All blinking
0x02 | 1 flashes, then on
0x03 | 2 flashes, then on
0x04 | 3 flashes, then on
0x05 | 4 flashes, then on
0x06 | 1 on
0x07 | 2 on
0x08 | 3 on
0x09 | 4 on
0x0A | Rotating (e.g. 1-2-4-3)
0x0B | Blinking*
0x0C | Slow blinking*
0x0D | Alternating (e.g. 1+4-2+3), then back to previous*

Cependant, avec l’analyseur USB nous ne voyons aucun message de ce type malgré le fait que la bonne LED est sélectionné sur la télécommande Xbox. Un coup d’œil dans le code source du pilote xpad du noyau linux à permit de trouvé que le rapport n’est pas sur 3 octets mais sur 12 et a le format suivant :

Position | Valeur
0x00 | 0x00
0x01 | 0x08
0x02 | 0x40 + (command % 0x0E)
0x03 | 0x00
0x04 | 0x00
0x05 | 0x00
0x06 | 0x00
0x07 | 0x00
0x08 | 0x00
0x09 | 0x00
0x0A | 0x00
0x0B | 0x00

Dans notre application, seulement le code 0x01 est utilisé car le pilote support seulement une télécommande Xbox. Cependant, l’implémentation du pilote permet l’utilisation de n’importe laquelle de ces commandes.

### 4.9.8 Vue d’ensemble du pilote USB

L’image suivante permet d’expliquer et de mettre en contexte le pilote USB qui a été développé.

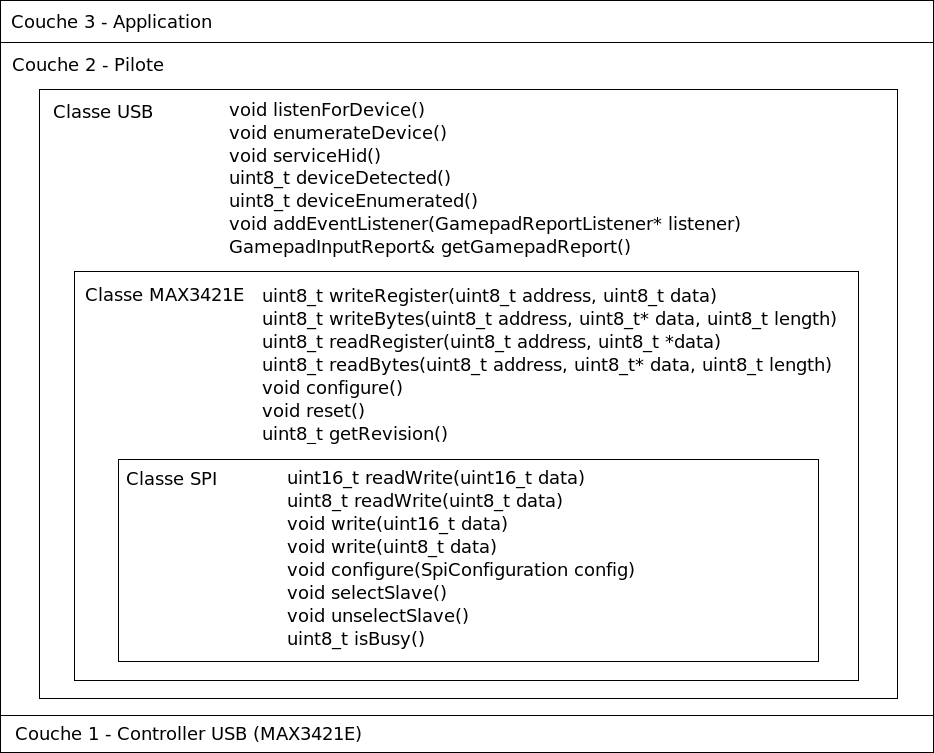
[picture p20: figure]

Un seul coup d’œil à ce diagramme permet de repérer les fonctions exposées de chacune des classes. Notez que l’utilisateur se situe à la couche application et ne fait des requêtes qu’à la classe USB.

### 4.9.9 Aparté – L’interface avec le Nintendo

Afin de faire une bonne démonstration du processus de réception des commandes, une interface avec le Nintendo fût développée. Cette interaction est intéressante car ceci démontre la possibilité des faire le traitement des commandes en temps réel. De plus, une fois les commandes reçues et décodées, nous arrivons à la frontière entre le travail des deux participants de l’équipe. Cette interface pourra donc servir d’exemple lors de l’intégration des deux sections.

Le principe de fonctionnement de cette interface est assez simple. En bref, le microcontrôleur fait l’émulation d’une manette de Nintendo tout en recevant les commandes de la télécommande Xbox.

Pour bien comprendre l’implémentation de l’émulation, il faut jeter un œil à l’intérieur d’une manette de Nintendo. Celle-ci est composée d’un simple convertisseur série-parallèle. Chaque bouton sont individuellement relié à une entré du convertisseur. De plus, ces boutons sont actif bas. En d’autres termes, lorsque nous appuyons sur un bouton, le signal de sortie est 0.

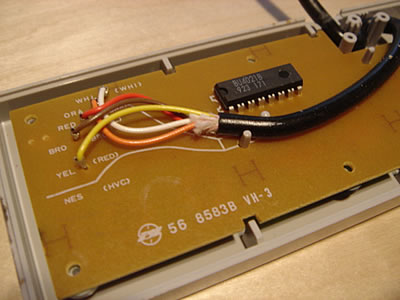
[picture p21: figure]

Pour communiquer avec la manette, le Nintendo utilise 3 signaux soit le Latch, l’horloge et le signal de sortie pour l’état des boutons. Le Latch permet d’indiqué à la télécommande qu’un transfère va bientôt commencer et que celle-ci doit entrer en mémoire les boutons présentement enfoncés. Ensuite le Nintendo envoie 8 impulsions sur le signal d’horloge et à chaque impulsion, la manette doit lui envoyé l’état d’un bouton sur la ligne de sortie. L’ordre des de l’envoie des boutons est prédéterminé et est le suivant : A, B, SELECT, START, UP, DOWN, LEFT, RIGHT.

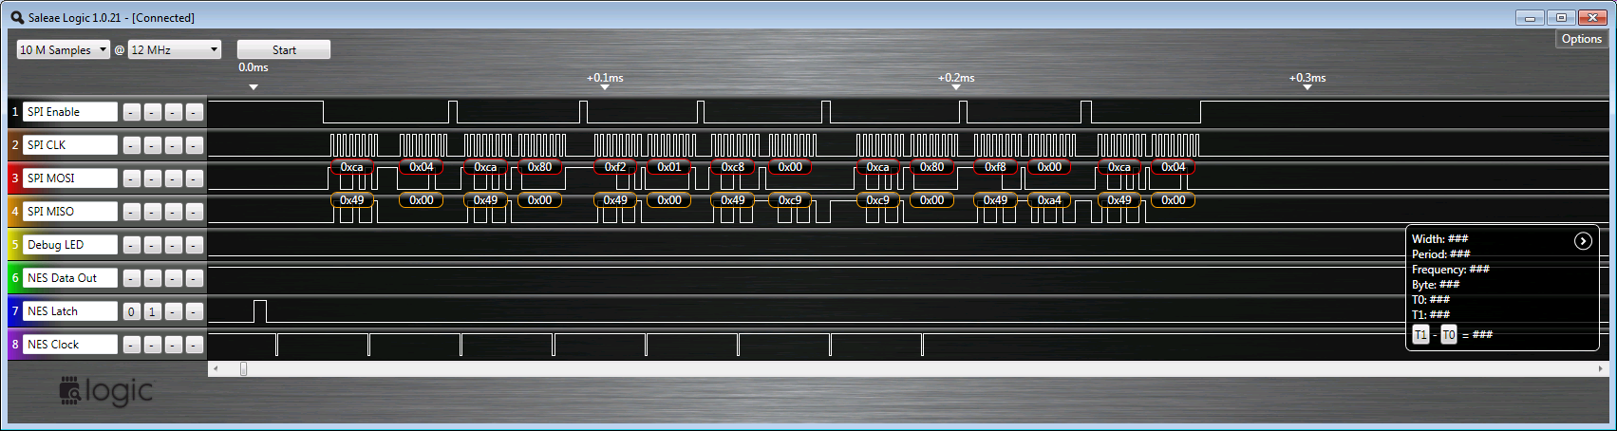
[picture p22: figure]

Comme vous pouvez le constaté, l’horloge est à l’était haut par défaut. Il est important de noté que selon plusieurs source sur internet, celle-ci est à l’état bas par défaut. Ceci est assez bizarre mais laisse croire que le Nintendo à subie quelques révisions durant son existance. De toute façon ceci ne change pas l’implémentation de l’interface.

Une autre chose importante à remarqué c’est quand bien que le Nintendo soit assez vieux, la communication entre la manette et celui-ci est très rapide. Le signal Latch à une largeur de 3.3 microsecondes et les impulsions d’horloge 0.5 microsecondes. D’autre part, la fréquence de l’horloge est de 38 kHz ce qui est assez facile à suivre. Le Nintendo demande l’état de la manette 60 fois par secondes.

Comme la télécommande de Xbox doit être vérifié 1000 fois par secondes et que le Nintendo demande l’état de la manette seulement 60 fois par seconde, nous sommes assuré d’envoyé des donnés fraiche au Nintendo. Cependant il est impossible de faire la synchronisation. Ceci ne cause pas de problème car il est très facile de faire les deux choses en même temps à l’aide d’interruptions.

Nous utilisons donc 2 interruptions externes. Une pour le Latch et l’autre pour l’horloge. Le principe est fort simple. À toutes les fois que la télécommande Xbox change d’état, elle envoie cette information au microcontrôleur par le biais du pilote USB. Le pilote décode ensuite ce rapport et l’envoie à l’interface du Nintendo qui s’est enregistré préalablement. L’interface conserve cette information sous un format pouvant être envoyé facile au Nintendo. D’un autre coté, lorsque l’interface reçoit une interruption venant du Latch, elle prend la dernière information reçue et en fait une copie pour le prochain transfère. Lors d’une interruption venant du signal de l’horloge, l’interface met l’état d’un bouton sur la ligne de sortie et prépare l’état du prochain bouton. Le diagramme de séquence suivant met en perspective cette communication.

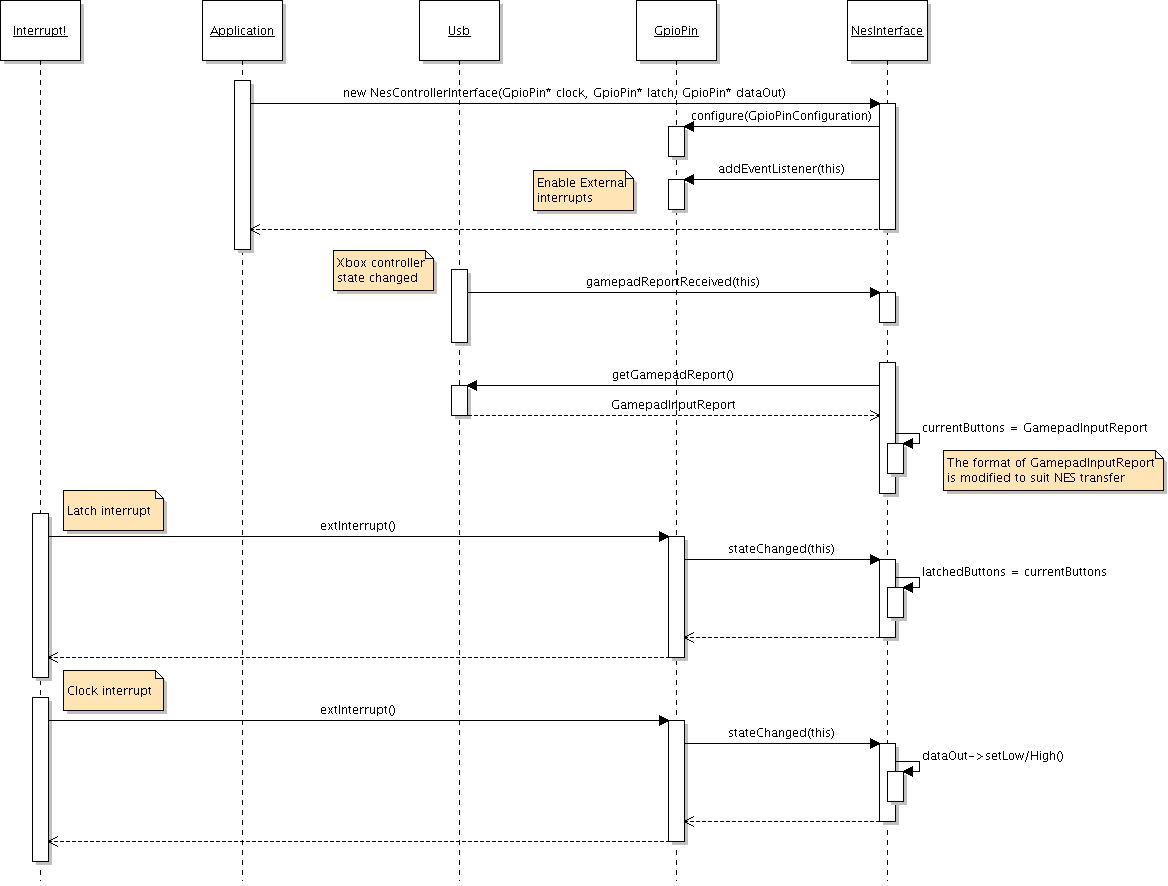
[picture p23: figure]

Cette implémentation fût testée sur une vraie plateforme Nintendo et permet un contrôle aussi fluide qu’avec la vraie manette d’origine.

# CHAPITRE 5 <titre>

## 5.1 <Titre>

<Texte>

# CHAPITRE 6 <titre>

## 6.1 <Titre>

<Texte>

# CHAPITRE 7 <titre>

## 7.1 <Titre>

<Texte>

# CHAPITRE 8 <titre>

## 8.1 <Titre>

<Texte>

# CHAPITRE 9 <titre>

## 9.1 <Titre>

<Texte>

# CHAPITRE 10 <titre>

## 10.1 <Titre>

<Texte>

# CONCLUSION

<Texte interligne 1 1/2>

# RECOMMANDATIONS <S’il y a lieu>

<Texte interligne 1 1/2>

ANNEXE I <titre>

<Texte>

ANNEXE II <titre>

<Texte>

ANNEXE III <titre>

<Texte>

ANNEXE IV <titre>

<Texte>

ANNEXE V <titre>

<Texte>

ANNEXE VI <titre>

<Texte>

ANNEXE VII <titre>

<Texte>

ANNEXE VIII <titre>

<Texte>

ANNEXE IX <titre>

<Texte>

ANNEXE X <titre>

<Texte>

# APPENDICES <S’il y a lieu>

<Texte>

# LISTE DE RÉFÉRENCES

USB Complete Fourth Edition

http://free60.org/wiki/GamePad

xboxdrv-linux - http://pingus.seul.org/~grumbel/xboxdrv/

Wireshark - http://www.wireshark.org/

Xpad

# BIBLIOGRAPHIE

<Texte – Style Références bibliographiques déjà activé>

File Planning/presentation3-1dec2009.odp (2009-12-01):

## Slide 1

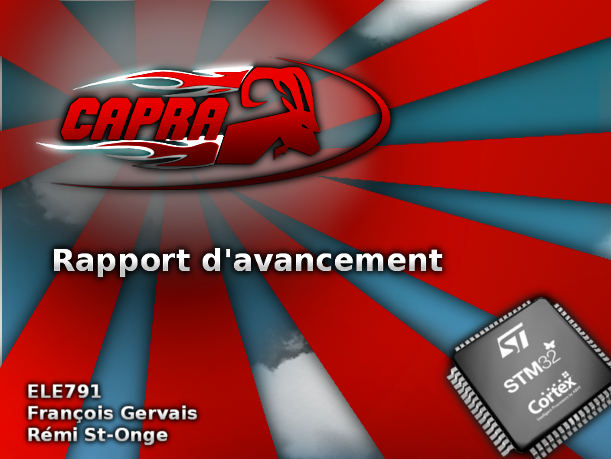
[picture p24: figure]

## Plan de la présentation

- Évolution depuis la dernière rencontre
    François
  - Selon la planification
  - En pratique
    Rémi
  - Selon la planification
  - En pratique
- Conclusions définitives au niveau du projet

François Gervais – Rémi St-Onge

## Évolution selon la planification

Section François

- Tâches qui devaient être accompli
  - Décodage des commandes
  - Vérification de la robustesse de la transmission sans fil

Voir diagramme de Gantt

François Gervais – Rémi St-Onge

## Évolution en pratique

Section François

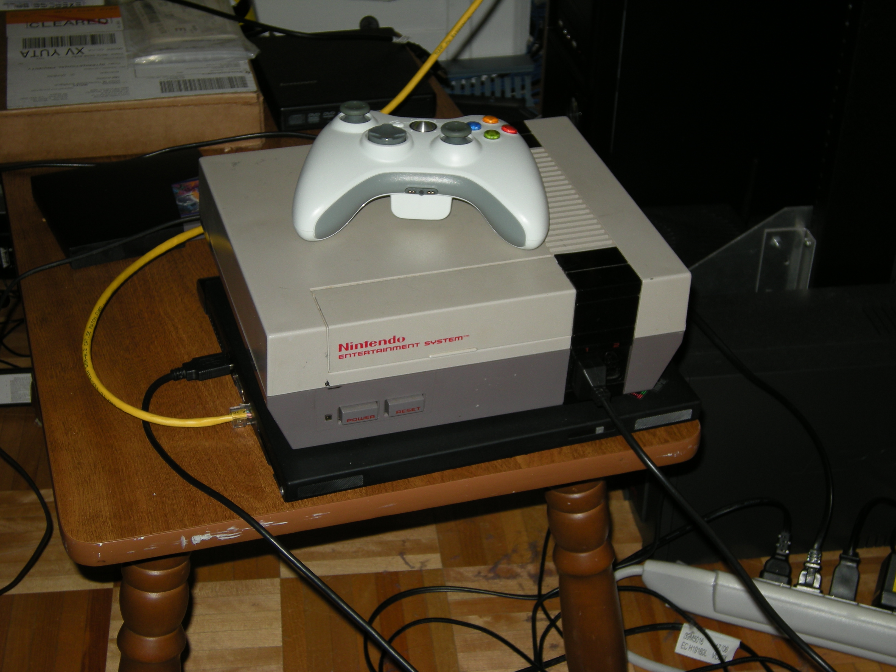
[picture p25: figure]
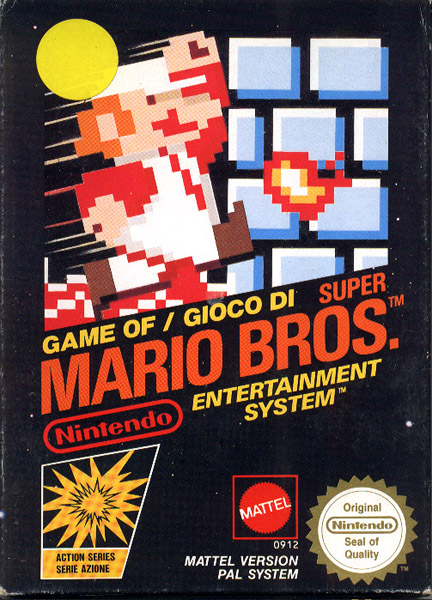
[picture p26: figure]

Voir diagramme de séquence et démonstration

François Gervais – Rémi St-Onge

## Conclusion

Section François

- Ce projet fût un des plus enrichissants auquel j'ai participé
- Développement des compétences suivantes :
  - USB
  - Linker script
  - Fichier de démarrage
  - Makefile

François Gervais – Rémi St-Onge

## Accomplissement selon la planification

Section Rémi

- Tâches qui devaient être accomplies
  - Dessin des schémas électriques
  - Design et conception du circuit imprimé
    - positionnement des pièces
    - forment de la carte
    - traçage des conducteurs

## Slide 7


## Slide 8


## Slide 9


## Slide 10


Section Rémi

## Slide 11


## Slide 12


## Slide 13


## Conclusion

Section Rémi

  Apprentissage :
- Programmation orientée objet dans un microcontrôleur
- Famille de microcontrôleur Arm
- Utilisation du logiciel Altium
  Ce projet aura aidé le club Capra à plusieurs niveaux :
- Perfectionnement des robots
- Documentation
- Transfert de connaissance avec les nouveaux

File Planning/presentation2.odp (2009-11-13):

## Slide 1


## Plan de la présentation

- Avancement depuis la dernière rencontre
  - Selon la planification
  - En pratique
- D'ici la prochaine rencontre
  - Objectifs
  - Stratégie adopté
- Conclusions hâtives face à l'accomplissement du projet

François Gervais – Rémi St-Onge

## Avancement selon la planification

Section François

- Tâches qui devaient être complêtées
  - Expérimentation avec divers controlleurs
  - Choix du contrôleur
  - Programmation d'un pilote
  - Test et déverminage du pilote
  - Décodage des commandes

Voir diagramme de Gantt

François Gervais – Rémi St-Onge

## Avancement en pratique

Section François


Voir diagramme de séquence et démo


François Gervais – Rémi St-Onge

## Objectifs et stratégie

Section François

- Terminer la gestion des rapports USB
- Faire les essais finaux
- Planification de l'intégration du système
- Début de la rédaction du rapport final

François Gervais – Rémi St-Onge

## Conclusion

Section François

- Le projet est sur la bonne voie et dans les temps
- Compte tenu des tests préliminaires, le système devrait être bien adapté aux besoins
- L'intégration du système sera probablement retardé dû au délai de manufacture du PCB

François Gervais – Rémi St-Onge

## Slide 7

Section Rémi

- Avancement depuis la dernière rencontre
  - Selon la planification
  - En pratique (retard)
- D'ici la prochaine rencontre
  - Objectifs

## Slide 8

Section Rémi

- Taches qui devaient être complétés
  - Communication RS232
  - Lecture PWM
  - Multiplexeur de source
  - Réorganisation des arrêts d'urgences
  - Réorganisation des récepteurs

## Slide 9

Section Rémi

- Taches qui devaient être complétés
  - Communication RS232: 80% complété
  - Lecture PWM: 5% complété
  - Multiplexeur de source: 70% complété
  - Réorganisation des arrêts d'urgences: 0% complété
  - Réorganisation des récepteurs:0% complété

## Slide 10

Section Rémi

- Objectifs et Stratégie
  - Réorganisation des arrêts d'urgences et des récepteurs sera fait par l'équipe de Capra lorsque le moment sera venu de câbler Herbinator.
  - Commencer le PCB est primordial, le code qui n'est pas terminé pourra être effectué pendant l'attente de la fabrication du PCB.
  - Début de la rédaction du rapport final

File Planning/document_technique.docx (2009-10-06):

# Document technique

# Analyse de la problématique

## Division en sous-problème

Vue d’un haut niveau, le problème est de contrôler le robot à l’aide d’une télécommande ou de commandes venant de l’intelligence artificiel. Il faut ensuite transformer ces commandes et les envoyer au robot.

Nous avons divisé ce problème sous la forme suivante:

- Implémentation d’une communication robuste entre une télécommande et le microcontrôleur.
- Développement d’une interface entre le récepteur actuel (PWM) et le microcontrôleur.
- Faire une gestion intelligente de ces deux sources de commande.
- Réorganisation des récepteurs.
- Réorganisation des arrêts d’urgence et des alimentations.

## Étude de la complexité

Lors de l’étude préliminaire, nous avons conclu que la façon la plus sûr de transmettre les commandes à distance serait de faire l’utilisation d’un protocole à haut débit comme le « bluetooth » ou un protocole utilisant la bande 2.4Ghz. Cette haute bande passante permettrait de gérer facilement les erreurs de transmission. Cependant, ces protocoles sont plus ardus à implémenter. Le reste des problèmes offrent une complexité moyenne.

Nous avons donc classé les problèmes dans cet ordre décroissant de complexité (Du plus complexe au moins complexe) :

1. Implémentation d’une communication robuste entre une télécommande et le microcontrôleur.
2. Développement d’une interface entre le récepteur actuel (PWM) et le microcontrôleur.
3. Réorganisation des récepteurs.
4. Réorganisation des arrêts d’urgence et des alimentations.
5. Faire une gestion intelligente de ces deux sources de commande.

# Choix d’une solution

## Jet d’idée

### Utilisation d’un microcontrôleur de type

- Atmel Atmega
- Microchip PIC
- ARM Cortex
- FPGA

### Utilisation d’une carte

- Préconstruite contenant le microcontrôleur.
- De notre conception

### Utilisation d’une télécommande de type

- Nintendo Entertainment System (NES)
- Xbox360
- Playstation3

## Définition des concepts

Après de longues réflexions, nous en sommes arrivé aux 4 concepts suivent :

Concept 1
Composant | Complexité /10 | Coût /10 | Efficacité /10
ARM Cortex-M3
Carte préconstruite
Télécommande Xbox

Concept 2
Composant | Complexité /10 | Coût /10 | Efficacité /10
ARM Cortex-M3
Carte de note conception
Télécommande PS3

Concept 3
Composant | Complexité /10 | Coût /10 | Efficacité /10
Atmega
Carte de note conception
Télécommande Xbox

Concept 4
Composant | Complexité /10 | Coût /10 | Efficacité /10
Atmega
Carte de note conception
Télécommande NES

## Concept retenu

Notre choix s’est arrêté sur le concept #1.

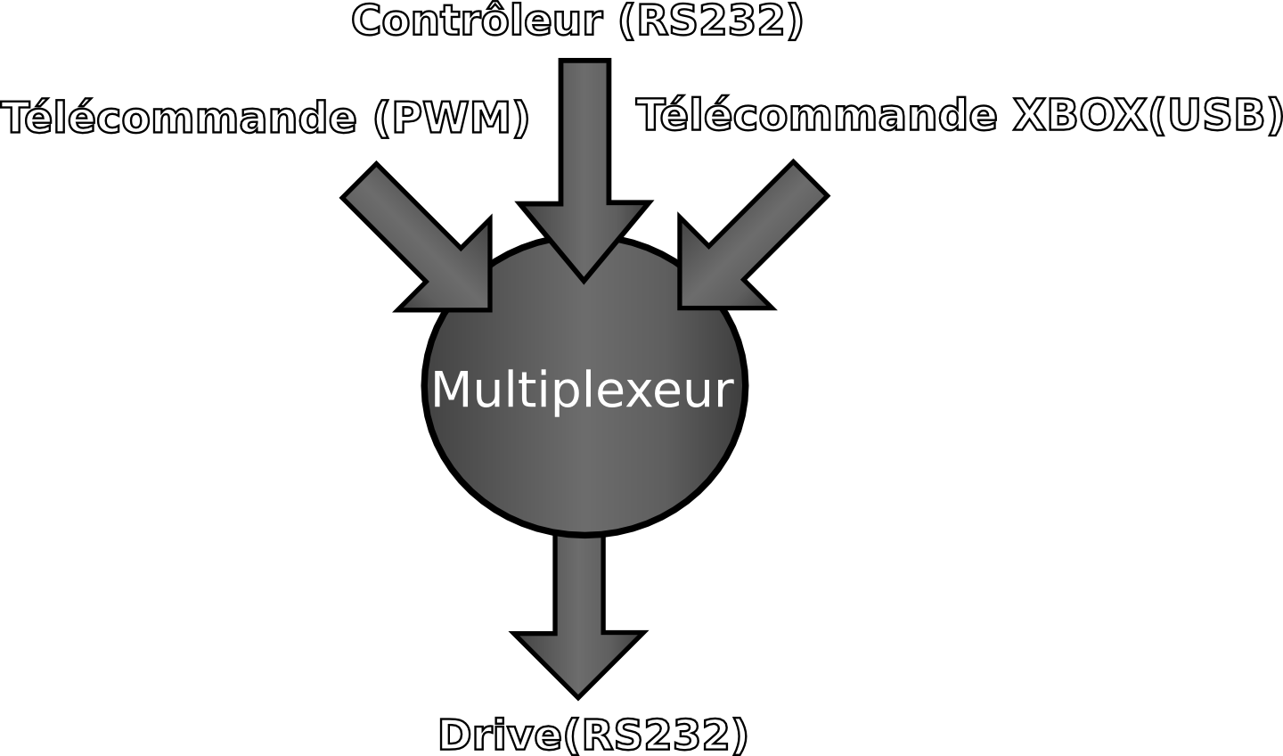
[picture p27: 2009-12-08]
Rapport/images/mux.png

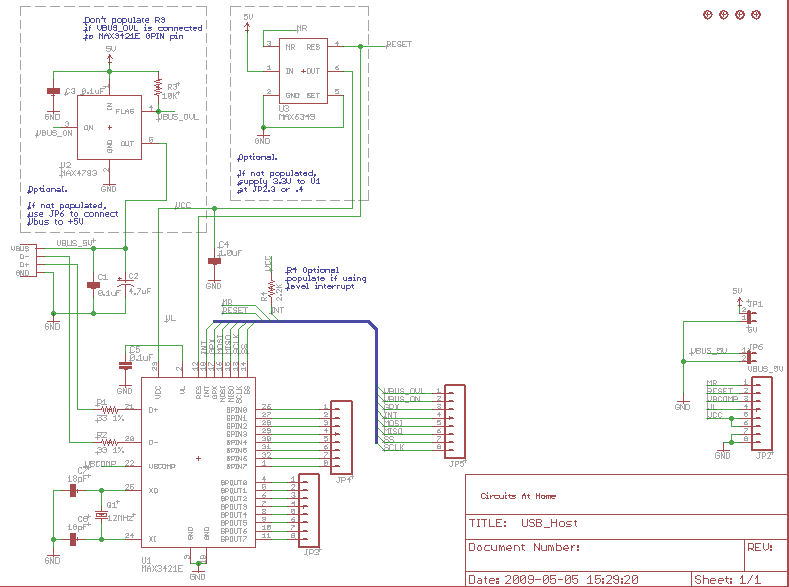
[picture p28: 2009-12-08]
Rapport/images/schema max4931.png

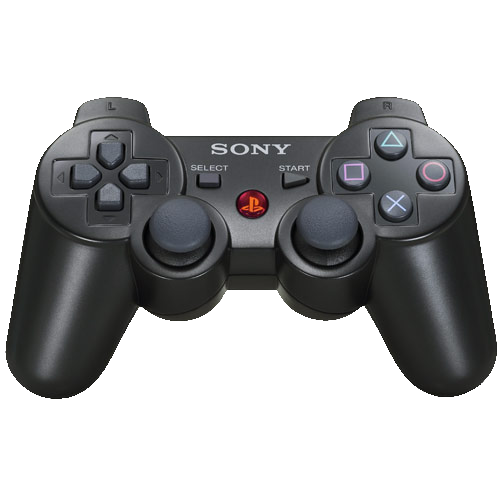
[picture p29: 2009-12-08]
Rapport/images/ps3_controller.png

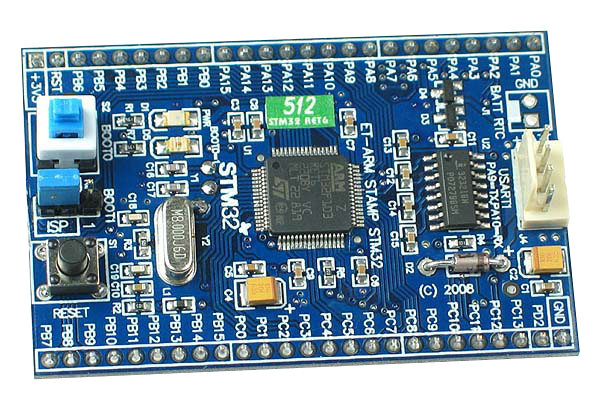
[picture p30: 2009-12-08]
Rapport/images/ET_ARM_STAMP_II_600.png

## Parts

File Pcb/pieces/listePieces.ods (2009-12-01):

Pièce | Description | #Digikey | package | Prix | Qty | pitch | prix total
Arm | MCU ARM 512KB FLASH MEM 64-LQFP | 497-6444-ND | 64-LQFP | 15,84 | 1 |  | 15,84
MAX3232CWE+ | IC DRVR/RCVR MULTCH RS232 16SOIC | 296-13099-1-ND | 16-SOIC (7.5mm Width) | 1,5 | 1 |  | 1,5
DB9 Femelle | CONN D-SUB RCPT R/A 9POS GOLD/FL | A35109-ND | Through Hole, Right Angle | 1,1 | 1 |  | 1,1
DB9 Male | CONN D-SUB PLUG R/A 9POS GOLD/FL | A35105-ND | Through Hole, Right Angle | 1,06 | 1 |  | 1,06
MAX3421E | controleur USB host | on l'a déja |  |  |  |  | 0
LT1587 | régulateur 3.3v | on l'a déja |  |  |  |  | 0
LM2575 | switching stepdown 24->12v & 24->5v | on l'a déja |  |  |  |  | 0
USBA | CONN RCPT USB TYPE A R/A GOLD | UE27AC54100-ND (http://search.digikey.com/scripts/DkSearch/dksus.dll?Detail&name=UE27AC54100-ND) |  | 0,85 | 1 |  | 0,85
LED ROUGE | LED 660NM RED DIFF 1206 SMD HSMH-C150 | 516-1439-1-ND |  | 0,5 | 5 |  | 2,5
LED VERT | LED 570NM GREEN DIFF 1206 SMD HSMG-C150 | 516-1443-1-ND (http://search.digikey.com/scripts/DkSearch/dksus.dll?Detail&name=516-1443-1-ND) |  | 0,5 | 6 |  | 3
condensateur 0.1µF | CAP .1UF 16V CERAMIC X7R 0603 | PCC1762CT-ND | 0603 (1608 metric) | 0,04 | 12 |  | 0,48
condensateur 0.1µf tantal | CAPACITOR TANT .10UF 35V 10% SMD | 399-3676-1-ND | 3216-18 (EIA) 1206 | 0,19 | 5 |  | 0,95
condensateur 22pf | CAP CERAMIC 22PF 50V 0603 SMD | PCC220ACVCT-ND | 0603 (1608 metric) | 0,09 | 2 |  | 0,18
condensateur 10pf | CAP CERAMIC 10PF 50V NP0 0603 | 399-1049-1-ND | 0603 (1608 metric) | 0,03 | 2 |  | 0,06
condensateur 18pf | CAP CERAMIC 18PF 50V NP0 0603 | 399-1052-1-ND | 0603 (1608 metric) | 0,31 | 2 |  | 0,62
condensateur 4.7µf | CAP TANTALUM 4.7UF 6.3V 10% SMD | 495-2177-1-ND | 3216-18 (EIA) 1206 | 0,18 | 1 |  | 0,18
condensateur 10µf tantal | CAP TANTALUM 10UF 16V 10% SMD | 495-2236-1-ND | 3216-18 (EIA) 1206 | 0,21 | 7 |  | 1,47
condensateur 100µf | CAP 100UF 16V ELECT VZ RADIAL | 493-1283-ND | Radial | 0,21 | 2 |  | 0,42
condensateur 330µf | CAP 330UF 25V ELECT VZ RADIAL | 493-1303-ND | Radial | 0,35 | 2 |  | 0,7
diode shotkey | DIODE SCHOTTKY 3A 40V DO-201AD | 1N5822GOS-ND | DO-201AD, Axial | 0,43 | 2 |  | 0,86
diode zener 3.3 | DIODE ZENER 500MW 3.3V DO35 | 1N5226B-TPCT-ND | DO-35, Axial | 0,33 | 1 |  | 0,33
 |  |  |  |  |  |  | 0
Crystal 8MHz | CRYSTAL 8.00 MHZ 20PF 49US | X1094-ND | HC49/US | 0,58 | 1 |  | 0,58
Crystal 32.768kHz | CRYSTAL 32.768KHZ 12.5PF CYL | 535-9032-ND | Cylinder | 0,25 | 1 |  | 0,25
Crystal 12MHz | CRYSTAL 12.000 MHZ SER 49US | X428-ND | HC-49US | 0,58 | 1 |  | 0,58
 |  |  |  |  |  |  | 0
Inductance 330µH | INDUCTOR 330 UH 5% 1812 SMD | PCD1471CT-ND | 1812 (4532 metric) | 0,49 | 2 |  | 0,98
 |  |  |  |  |  |  | 0
Résistance 33ohm 1% | RES 33 OHM 1/16W .5% 0603 SMD | RR08Q33DCT-ND | 0603 (1608 metric) | 0,1 | 2 |  | 0,2
Résistance 55ohm | RES 54.9 OHM 1/10W 1% 0603 SMD | RMCF1/1654.9FRCT-ND | 0603 (1608 metric) | 0,04 | 2 |  | 0,08
Résistance 75ohm | RES 75 OHM 1/10W 1% 0603 SMD | RMCF1/1675FRCT-ND | 0603 (1608 metric) | 0,04 | 2 |  | 0,08
Résistance 160ohm | RES 160 OHM 1/10W 5% 0603 SMD | RMCF1/16160JRCT-ND | 0603 (1608 metric) | 0,02 | 1 |  | 0,02
Résistance 500ohm | RES 560 OHM 1/2W 5% 1210 SMD | RMCF1/4560JRCT-ND | 1210 (3225 metric) | 0,21 | 2 |  | 0,42
Résistance 1k 1/2W | RES 1.0K OHM 1/2W 5% 1210 SMD | P1.0KVCT-ND | 1210 (3225 metric) | 0,27 | 1 |  | 0,27
Résistance 1k 1/10W | RES 1K OHM 1/10W 1% 0603 SMD | RMCF1/161KFRCT-ND | 0603 (1608 metric) | 0,04 | 1 |  | 0,04
Résistance 10k | RES 10K OHM 1/10W 1% 0603 SMD | RMCF1/1610KFRCT-ND | 0603 (1608 metric) | 0,04 | 1 |  | 0,04
Résistance 1M | RES 1M OHM 1/10W 1% 0603 SMD | RMCF1/161MFRCT-ND | 0603 (1608 metric) | 0,04 | 1 |  | 0,04
 |  |  |  |  |  |  | 0
Power Connector Socket | CONN HEADER 2POS R/A W/CLIP GOLD | WM1875-ND | Through Hole, Right Angle | 1,62 | 1 | 0.118" (3.00mm) | 1,62
Power Connecteur Wire | CONN RECEPT 2POS 3MM SINGLE ROW | WM1845-ND | Free Hanging (In-Line) | 0,48 | 1 | 0.118" (3.00mm) | 0,48
Pin male 0.118mm |  |  |  | 0,15 | 10 | 0.118" (3.00mm) | 1,5
Pin femelle 0.118mm | CONN SOCKET 20-24AWG GOLD CRIMP | A32523-ND |  | 0,15 | 10 | 0.118" (3.00mm) | 1,5
connecteur PWM Socket et NES | CONN HEADER 4POS R/A W/O PEGS | A30615-ND | Through Hole, Right Angle | 0,67 | 2 | 0.165" (4.20mm) | 1,34
Connecteur PWM wire | CONN RECEPT 4POS W/POSTIVE LOCK | 106527-4-ND | Free Hanging (In-Line) | 0,35 | 2 | 0.165" (4.20mm) | 0,7
 |  |  |  |  |  |  | 0
Reset Tack switch | 6MM LIGHT TOUCH SWITCH 250GF | P8009S-ND | Through Hole | 0,29 | 1 |  | 0,29
Boot0 DPDT switch | SWITCH PB DPDT ALT ACT.1A PC MNT | EG1872-ND | Through Hole | 1,03 | 1 |  | 1,03
 |  |  |  |  |  |  | 0
Nes Buffer | IC LATCH OCTAL 3-STATE 20-SOIC | MM74HCT573WM-ND | 20-SOIC (7.5mm Width) | 0,49 | 1 |  | 0,49
Nes Connector Socket | CONN HEADER 4POS DUAL R/A TIN | A33253-ND | Through Hole, Right Angle | 1,02 | 1 | 0.118" (3.00mm) | 1,02
Nes Connecteur Wire | CONN RCPT 3MM 4POS DL MATE-N-L | A30294-ND | Free Hanging (In-Line) | 0,35 | 1 | 0.118" (3.00mm) | 0,35
 |  |  |  |  |  | total | 46 | $

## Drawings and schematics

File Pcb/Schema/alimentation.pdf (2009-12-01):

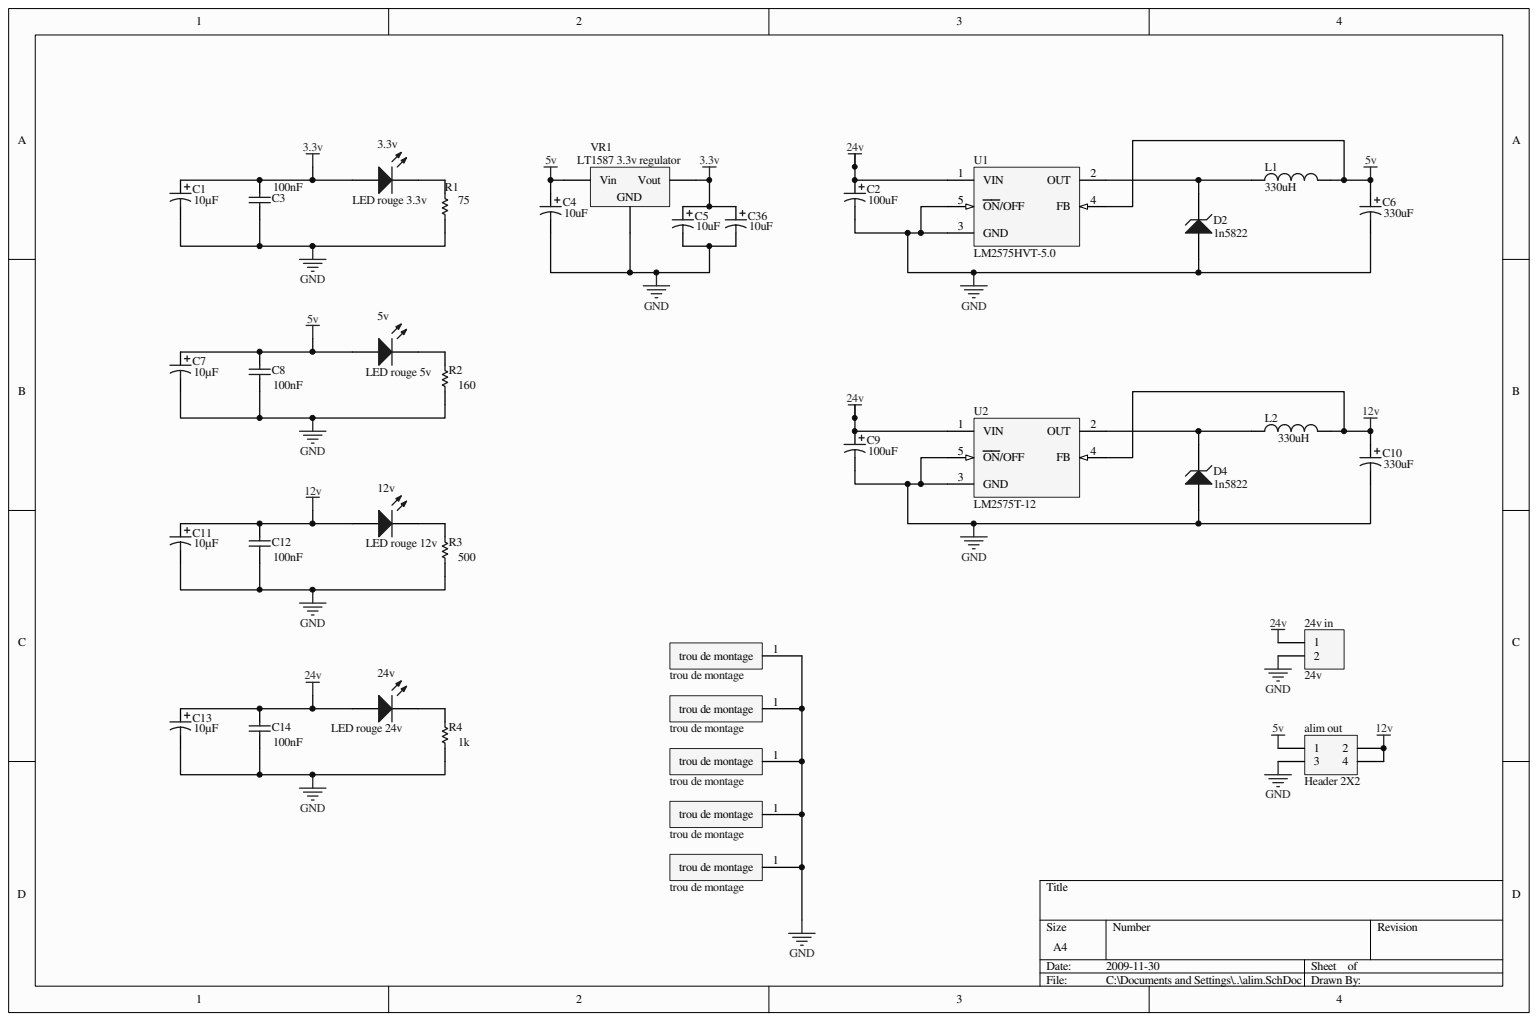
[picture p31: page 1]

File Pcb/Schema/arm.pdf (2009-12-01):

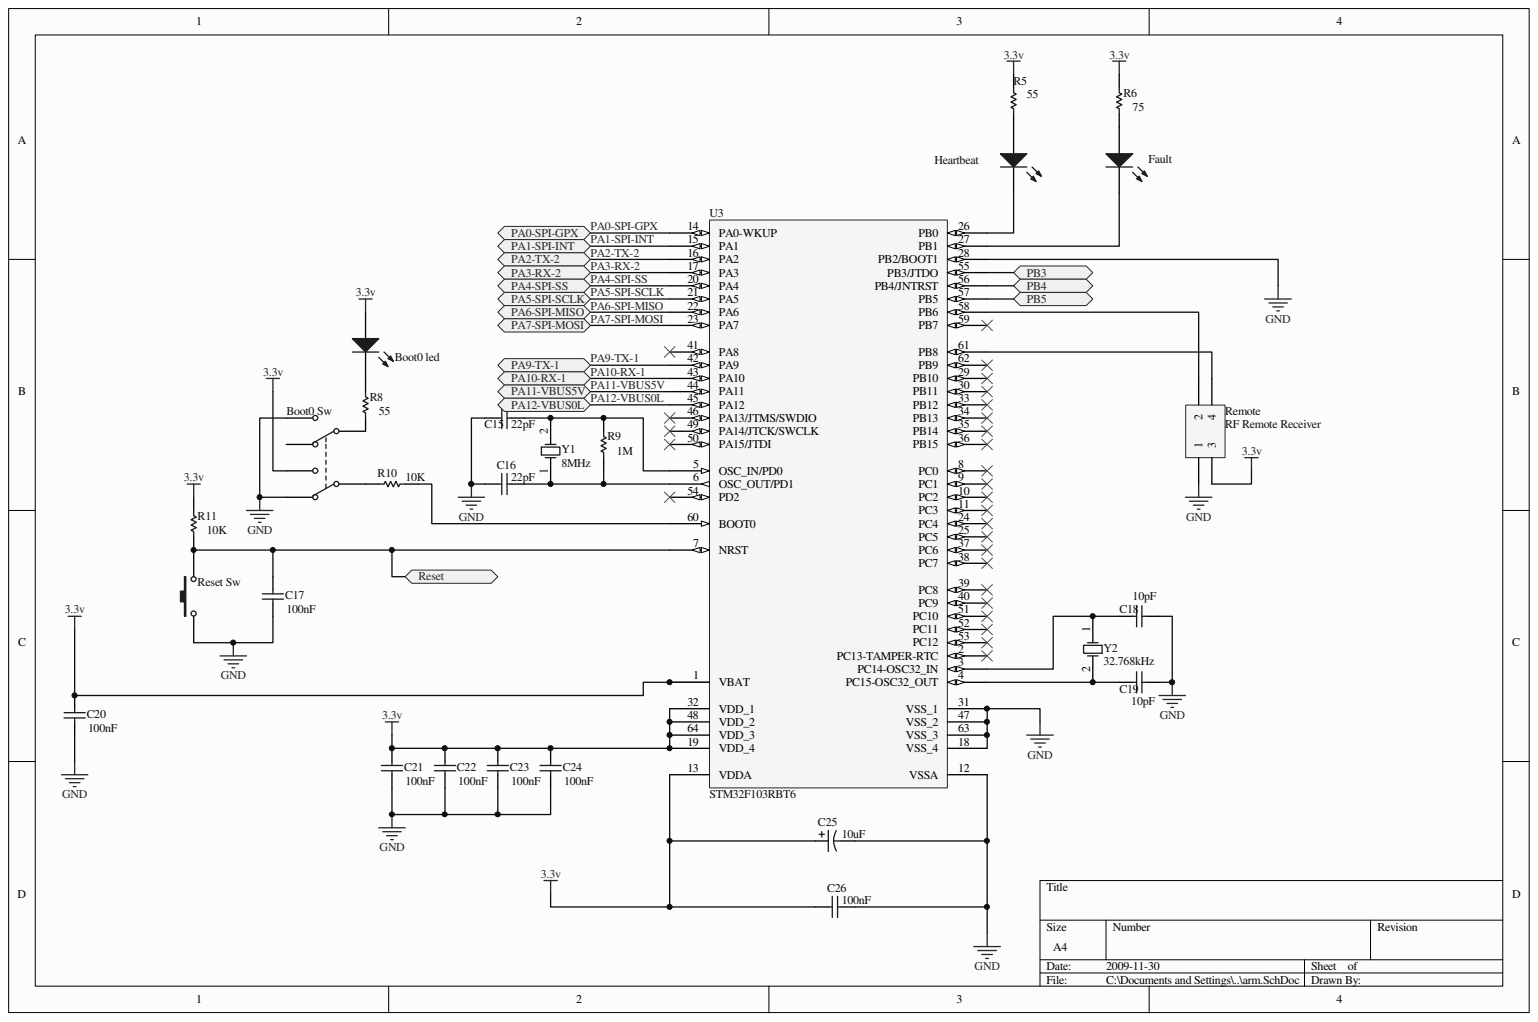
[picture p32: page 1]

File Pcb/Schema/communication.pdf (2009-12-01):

Q8 | 12 Q7 | 13 Q6 | 14 Q5 | 15 Q4 | 16 Q3 | 17 Q2 | 18 Q1 | 19

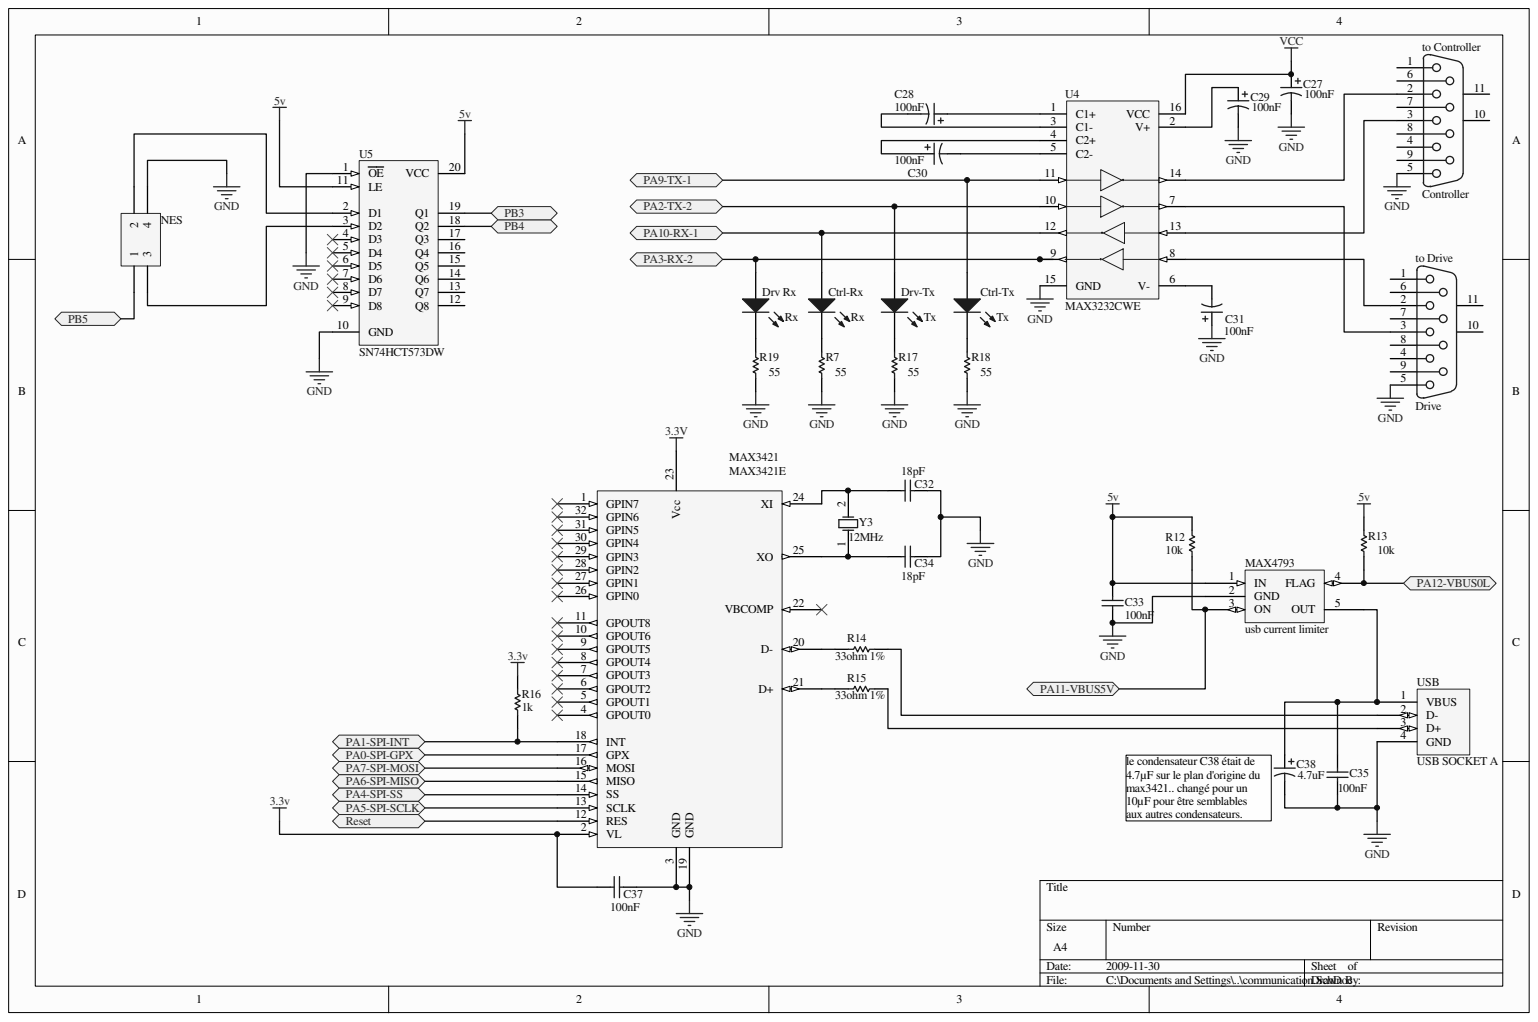
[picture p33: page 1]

4.7µF sur le plan d'origine du
max3421.. changé pour un
10µF pour être semblables
aux autres condensateurs.

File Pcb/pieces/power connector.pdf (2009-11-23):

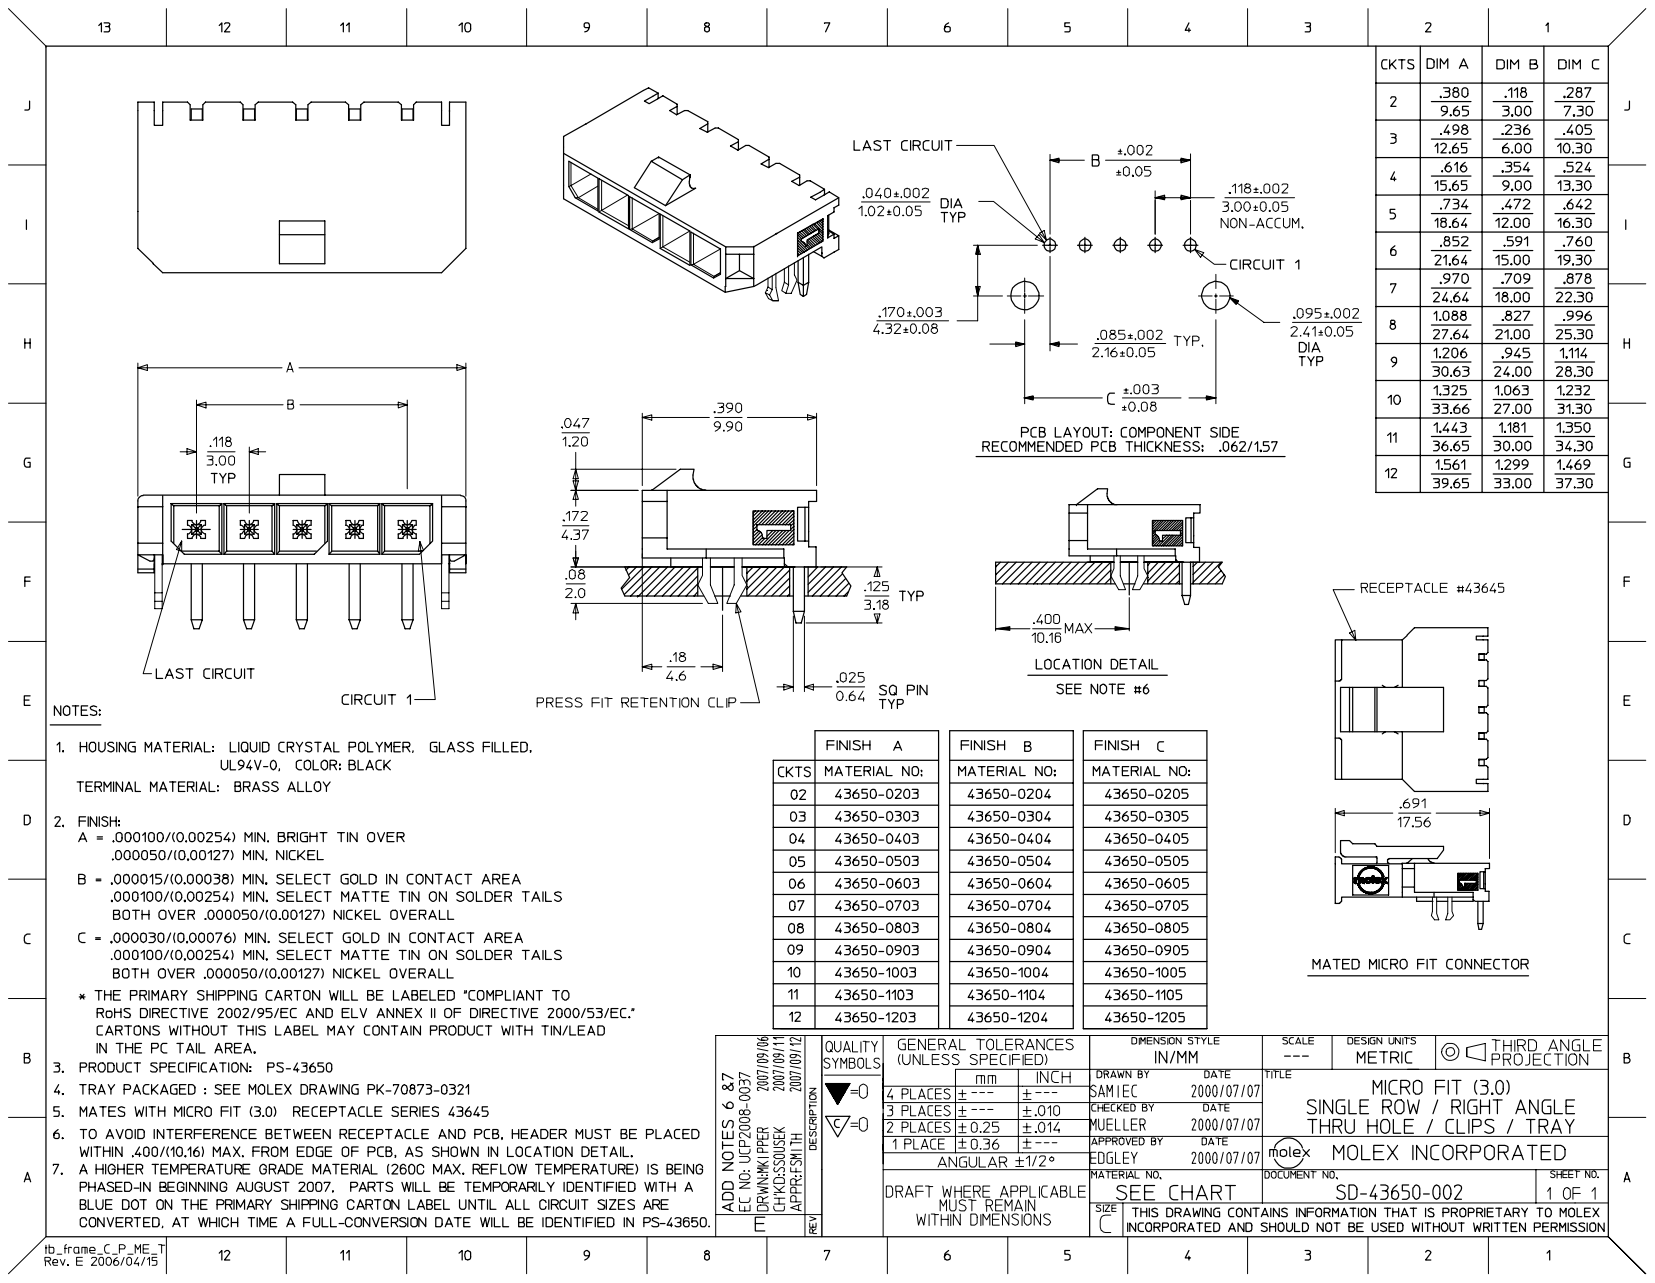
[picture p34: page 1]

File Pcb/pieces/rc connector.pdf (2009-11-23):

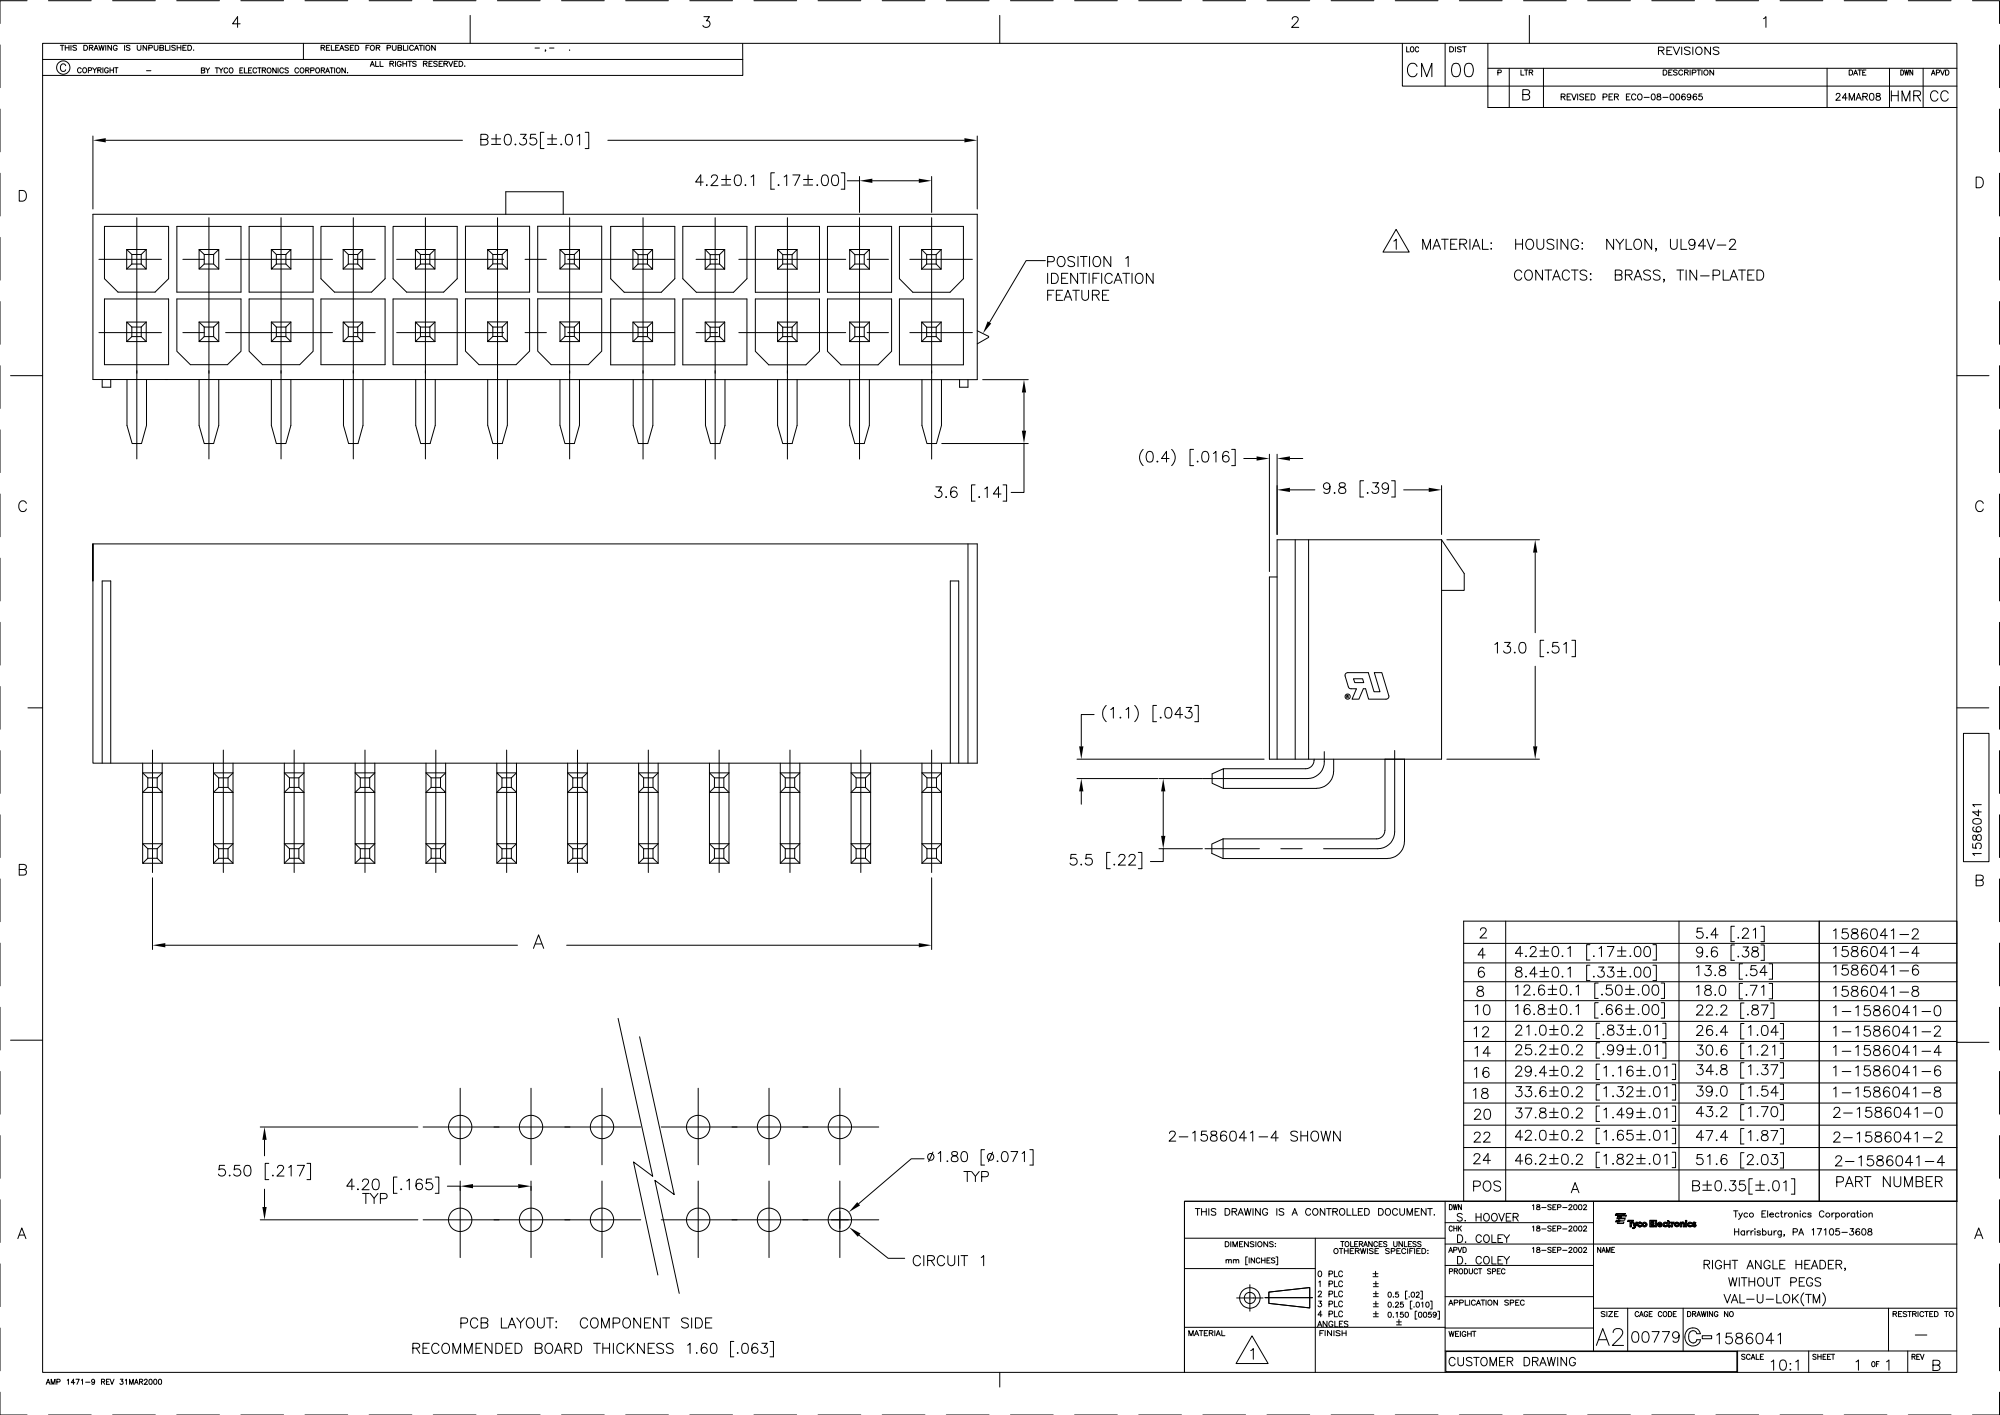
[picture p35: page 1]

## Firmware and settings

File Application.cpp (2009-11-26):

/*
 * Application.cpp
 *
 *  Created on: 2009-09-29
 *      Author: oex
 */

#include "STM32F103.h"
#include "GpioConfiguration.h"
#include "GpioPinConfiguration.h"
#include "GpioPin.h"
#include "Gpio.h"
#include "Uart.h"
#include "UartConfiguration.h"
#include "Usb.h"
#include "NesControllerInterface.h"

#include <stdint.h>

void main_francois();
void main_remi();
void blinky();

int main(void) {
	main_francois();
	//main_remi();
	//blinky();
}

void main_francois() {
	// Setup STM32 system (clock, PLL and Flash configuration)
	SystemInit();

	Gpio *gpioA = STM32F103::getGpioA();
	Gpio *gpioB = STM32F103::getGpioB();
	Gpio *gpioC = STM32F103::getGpioC();

	// Set default port behavior
	GpioConfiguration portConfig(Gpio::FLOATING_INPUT);
	gpioA->configure(portConfig);

	// Configure blinking led
	GpioPinConfiguration ledPinConfig;
	ledPinConfig.pin = Gpio::GP_PUSH_PULL_OUTPUT | Gpio::OUTPUT_SPEED_50MHZ;
	gpioA->getPin(0)->configure(ledPinConfig);

	GpioPin *led = gpioA->getPin(0);

	// Create the usb port
	Usb* usb = STM32F103::getUsb();

	// Create a new NES controller interface
	AFIO->MAPR |= AFIO_MAPR_SWJ_CFG_DISABLE;	// JTAG remap
	NesControllerInterface* nesInterface = new NesControllerInterface(gpioB->getPin(3), gpioB->getPin(4), gpioC->getPin(5));
	usb->addEventListener(nesInterface);

	usb->listenForDevice();

	while(!usb->deviceDetected());

	//debug
	// Blink led fast
	led->setHigh();	// On
	for(uint32_t i=0; i<100000; i++);
	led->setLow();	// Off
	for(uint32_t i=0; i<100000; i++);

	usb->enumerateDevice();

	// Blink led
	while(1) {

		//if(usb->deviceDetected()) {
			/*led->setHigh();	// On
			for(uint32_t i=0; i<100000; i++);
			led->setLow();	// Off
			for(uint32_t i=0; i<100000; i++);*/

			//if(!usb->deviceEnumerated()) {

				//debug
				// Blink led fast
				/*GPIOA->BSRR |= 0x01;	// On
				for(uint32_t i=0; i<100000; i++);
				GPIOA->BRR |= 0x01;	// Off
				for(uint32_t i=0; i<100000; i++);

				usb->enumerateDevice();*/
			//}
			//else {
				usb->serviceHid();
			//}
		//}

		/*
		led->setHigh();	// On
		for(uint32_t i=0; i<1000000; i++);

		led->setLow();	// Off
		for(uint32_t i=0; i<1000000; i++);
		*/

		// Simulate an external interrupt
		//EXTI->SWIER |= EXTI_SWIER_SWIER1;
	}
}

void main_remi() {
	char buf[27] = {'a', 'b', 'c', 'd', 'e', 'f', 'g', 'h', 'i', 'j', 'k', 'l', 'm' ,'n', 'o', 'p' ,'q'
	,'r', 's','t','u','v','w','x','y','z',' '};
	// Setup STM32 system (clock, PLL and Flash configuration)
	SystemInit();





	Gpio *gpioA = STM32F103::getGpioA();
	// Set default port behavior
	GpioConfiguration portConfig(Gpio::AF_PUSH_PULL_OUTPUT | Gpio::OUTPUT_SPEED_50MHZ);
	gpioA->configure(portConfig);

	Uart *uart1 = STM32F103::getUart1();
	UartConfiguration uart1Config;
	uart1Config.baudrate 		= 9600;
	uart1Config.stopBit 		= Uart::UART_1_STOPBIT;
	uart1Config.parityEnable 	= Uart::UART_PARITY_DISABLE;
	uart1Config.wordLenght		= Uart::UART_WORD_LENGTH_8BIT;
	uart1->configure(uart1Config);

	//Uart *uart2 = STM32F103::getUart2();
	// Uart2 config

	// Tag each Uart with their respective source
	uart1->setTag(Peripheral::Controller);
	//uart2->setTag(Peripheral::Drive);

	// Configure blinking led
	GpioPinConfiguration ledPinConfig;
	ledPinConfig.pin = Gpio::GP_PUSH_PULL_OUTPUT | Gpio::OUTPUT_SPEED_50MHZ;
	gpioA->getPin(0)->configure(ledPinConfig);

	GpioPin *led = gpioA->getPin(0);

	// Blink led
	while(1) {
		led->setHigh();	// On
		for(uint32_t i=0; i<1000000; i++){
			uart1->poll();
		}

		uart1->write((char *)buf, 27);

		led->setLow();	// Off
		for(uint32_t i=0; i<1000000; i++){
			uart1->poll();
		}
	}
}

void blinky() {
	// Setup STM32 system (clock, PLL and Flash configuration)
	SystemInit();

	Gpio *gpioA = STM32F103::getGpioA();

	// Configure blinking led
	GpioPinConfiguration ledPinConfig;
	ledPinConfig.pin = Gpio::GP_PUSH_PULL_OUTPUT | Gpio::OUTPUT_SPEED_50MHZ;
	gpioA->getPin(0)->configure(ledPinConfig);

	GpioPin *led = gpioA->getPin(0);

	while(1) {
		led->setHigh();	// On
		for(uint32_t i=0; i<1000000; i++);
		led->setLow();	// Off
		for(uint32_t i=0; i<1000000; i++);
	}
}

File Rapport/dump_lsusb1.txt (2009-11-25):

 
Endpoint Descriptor:
        bLength                 7
        bDescriptorType         5
        bEndpointAddress     0x81  EP 1 IN
        bmAttributes            3
          Transfer Type            Interrupt
          Synch Type               None
          Usage Type               Data
        wMaxPacketSize     0x0020  1x 32 bytes
        bInterval               1

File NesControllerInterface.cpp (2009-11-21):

/*
 * NesControllerInterface.cpp
 *
 *  Created on: Nov 18, 2009
 *      Author: fgervais
 */

#include "NesControllerInterface.h"
#include "GpioPin.h"
#include "Gpio.h"
#include "GamepadInputReport.h"
#include "GpioPinConfiguration.h"
#include "Usb.h"

NesControllerInterface::NesControllerInterface(GpioPin* clock, GpioPin* latch, GpioPin* dataOut) {
	this->clock = clock;
	this->latch = latch;
	this->dataOut = dataOut;

	latchedButtons = 0;
	currentButtons = 0;

	GpioPinConfiguration pinConfig;

	pinConfig.pin = Gpio::PULLUP_PULLDOWN_INPUT;
	clock->configure(pinConfig);
	clock->setLow();	// set pull-down
	pinConfig.pin = Gpio::PULLUP_PULLDOWN_INPUT;
	latch->configure(pinConfig);
	latch->setLow();	// set pull-down
	pinConfig.pin = Gpio::GP_PUSH_PULL_OUTPUT | Gpio::OUTPUT_SPEED_50MHZ;
	dataOut->configure(pinConfig);

	// Register for Gpio event
	latch->addEventListener(this);
	clock->addEventListener(this);
}

NesControllerInterface::~NesControllerInterface() {

}

void NesControllerInterface::stateChanged(GpioPin* pin) {

	if(pin->getPinNumber() == latch->getPinNumber()) {
		latchedButtons = currentButtons;
	}
	else {
		if((latchedButtons & 0x01)) {
			dataOut->setLow();
		}
		else {
			dataOut->setHigh();
		}

		latchedButtons = latchedButtons >> 1;
	}

}

void NesControllerInterface::gamepadReportReceived(Usb* usb) {
	GamepadInputReport gamepadReport;
	gamepadReport = usb->getGamepadReport();

	if(gamepadReport.back & 0x01) {
		GPIOA->BSRR |= 0x01; // On
	}
	if(!gamepadReport.back & 0x01) {
		GPIOA->BRR |= 0x01;	// Off
	}

	currentButtons = (gamepadReport.x) | (gamepadReport.back << 1) | (gamepadReport.start << 2)
		| (gamepadReport.dPadUp << 3) | (gamepadReport.dPadDown << 4) | (gamepadReport.dPadLeft << 5)
		| (gamepadReport.dPadRight << 6) | (gamepadReport.a << 7);
}

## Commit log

2009-10-01 Add Reference (Manuel, schematics and software manuel) and Planning (Gantt project, UML design..)
2009-10-01 Makefile now include wildcard for cpp files Uart class implementation is barely started
2009-10-02 Makefile has been modified so all the code (including the C code) is compiled with G++. This should avoid some problems in the future. STM32F103 class is the actual implementation of the mcu we are u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
2009-10-02 Makefile has been modified to the extended listing (.lss) is no longer generated. The build time is now way faster. If needed, the extended listing can be built separately. Every other file has been 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
    [Application.cpp]
2009-10-02 GpioPin class has been created to represent an actual pin on the chip. The makefile has been modified to it doesn't have the -Wshadow option anymore. It was anoying since I shadow members all the tim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
    [GpioPin.cpp]
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2009-10-04 GpioConfiguration has been renamed to GpioInitialization Kernel class is no longer needed and has been deleted main() function is void for now Gpio has been changed to take out generic stuff STM32F10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
    [Application.cpp, Gpio.cpp]
2009-10-04 All autogenerated TODO have been removed in order to use the task list. Uart interrupt handling pattern have been done Gpio now have the complete constant list.
2009-10-04 Brief: The gpio section has been completed but not tested. main() now blink a led on GpioA0.
    Details:
    GpioInitialization has been re-renamed to GpioConfiguration. It makes more sens with the datasheet. I won't rename it again.
    GpioPinConfiguration has been created in order to configure only one pin. Usage is exactly the same as GpioConfiguration. (Should use Gpio class constants)
    [Application.cpp, Gpio.cpp, GpioPin.cpp]
2009-10-06 led qui FLASH! corrigé des petits bugs de rien
    [Application.cpp, Gpio.cpp]
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2009-10-07 Modified Uart constant so the project compile. Added a constructor to GpioConfiguration so it includes a default value specification. Started the PheripheralEventListener section.
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2009-10-11 USART is now auto-detecting the system clock and is able to transmit character chain in polling mode
2009-10-12 UartConfig has been renamed to UartConfiguration for the sake of consistency. parityEnable and parityType have been removed to make to code compile
2009-10-13 merging conflict (solving my error.. :P)
    [Application.cpp]
2009-10-14 uart is now transmitting with the new Queue.h in interrupt mode
2009-10-14 uart tx working but with only small string.. dont know why..
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2009-10-15 Gpio and Uart now take care of freeing the memory in there destructor. Queue now handle pointers and not actual objects. NOTE: This needs to be tested. Some comments have been added in the Vector cla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
2009-10-18 configRegister variable of Gpio was not reset before servicing port configuration high register. Now it is.
    [Gpio.cpp]
2009-10-18 All the SPI configuration including the IO config have been send to STM32F1103 Peripheral now receive and optional ID by a constructor First version of MAX3421E write functions are done
2009-10-21 A lot of stuff have changed. Gpio now knows its port number. GpioPin is mostly ready to receive a external interrupt. GpioPinEventListener abstract class has been created so object can listen of exte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
2009-10-21 Gpio external interrupt handling is done except the interrupt handler itself in the C file that is only temporary. The Usb is now created but does nothing. This is the next implementation step.
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2009-10-23 Uart read and write are working in polling :D
2009-10-24 modify the UML for the uart, implement Command, Mux and CommandReceiver
2009-10-25 Usb should now be able to detect a connected and disconnected device
2009-11-01 Usb *should* be able to request interrupt report. Some testing is needed.
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2009-11-04 Usb section has been rearanged to match UML which was better
    [ConfigurationDescriptor.h]
2009-11-04 Minor changes to work with Uart new constructor
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2009-11-04 remove OutputStreamCommand from UML, remove enum that link peripheral to a external device
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2009-11-04 Some more descriptor added
    [ConfigurationDescriptor.h]
2009-11-05 The most important descriptors are done and UML has been updated accordingly.
    [ConfigurationDescriptor.h]
2009-11-06 Extrenal interrupt is now working at 100% (from 0 to 15)
2009-11-06 Timer counter functionnality has been implemented and integrated into Usb class to allow periodic interrupt services.
2009-11-06 Small typo corrected and UML updated
    [Timer.cpp]
2009-11-07 The timer interrupt/event system is now tested and is working like a charm
2009-11-09 If the uart section is uncommented, nothing is working anymore
2009-11-10 uart is now working.. (just re-order some thing.. in realty i did'nt change anything...)
2009-11-10 uart working in read and write.. the actual code is doing only a echo and print the letter 'a' each second
2009-11-10 Spi is now working correctly but some modifications still need to be done is Spi class.
    [Application.cpp, MAX3421E.cpp, Spi.cpp]
2009-11-10 Added write() functions to Spi class Modified existing readWrite() functions
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2009-11-13 create PCB folder and start working on the PCB
    [arm.SchDoc, remote.PrjPCB]
2009-11-14 Create alim schematic and populate the arm schematic
    [USB_Host.brd, USB_Host.sch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]
2009-11-15 USB has so many bug fixe and new features. A controller can now synchronize on the wireless receiver.
2009-11-15 add connector schematic
    [arm.SchDoc, connector.SchDoc, remote.PrjPCB]
2009-11-17 start to build a partlist and to get some datasheet
    [arm.SchDoc, connector.SchDoc, listePieces.ods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]
2009-11-18 Usb seems to be working flawles with a lot of these lines in the receiveRawData() function : // Clear the receive IRQ and free the buffer controller->writeRegister(MAX3421E::HIRQ, MAX3421E::HIRQ_RCVD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
2009-11-18 UML updated. NES interface created and mostly done Led are now changing state using the NES interface USB class now support listener on gamepad report Some cleaning done in the USB classes
2009-11-21 The NES interface is now working. *The vector class is known as buggy*
    [Application.cpp, GpioPin.cpp, NesControllerInterface.cpp]
2009-11-23 Schematic is now pretty complete and bill of materiel is up to date
    [alim.SchDoc, arm.SchDoc, communication.SchDoc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]
2009-11-25 Added a first version of the (French) final report
    [dump_lsusb1.txt]
2009-11-26 Final report updated
    [etude_facteur_utilisation.xlsx]
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2009-11-26 start to build physically the board
    [alim.SchDoc, arm.SchDoc, board.PcbDoc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]
2009-11-29 all pieces are now placed on the board.. but the board is really to big. will try to reduce his size.
    [Inductor Radial 283mil lead 118mil.PcbLib, RC NES connector.PcbLib, SOT95P280X145-5N.PcbLib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]
2009-12-01 * PCB is done! * add all schematics and picture in pdf and png format * add Power point presentation
    [alim.SchDoc, arm.SchDoc, board.PcbDoc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]
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2009-12-09 add a Questions slide.. and change the 2 bloc schematics picture for zoomed one.
2010-01-06 solve some trouble with the silkscreen of the pcb
    [RC NES connector.PcbLib, arm.SchDoc, board.PcbDoc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]
2010-02-10 MON PUTAIN DE PCB EST ENNNFIN FINI MANNE WOUUUUAHHH LABO CIRCUIT ME VOIIILA!!
    [5v et 12v connector.PcbLib, PcbLib1.PcbLib, PcbLib2.PcbLib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]
